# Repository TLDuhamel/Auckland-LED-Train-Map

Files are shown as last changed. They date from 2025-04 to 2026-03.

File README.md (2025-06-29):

# Auckland Live LED Train Map





**You can now support my work by buying this through my store:** [**https://keastudios.co.nz/store/akl-ltm/**](https://keastudios.co.nz/store/akl-ltm/)

A physical, real-time LED map of the Auckland train network, powered by an ESP32-C3 microcontroller. Train movements are displayed using addressable RGB LEDs, with live data fetched over Wi-Fi.

---

## Table of Contents

- [Auckland Live LED Train Map](#auckland-live-led-train-map)
  - [Table of Contents](#table-of-contents)
  - [Features](#features)
  - [Hardware](#hardware)
  - [PCB Design](#pcb-design)
  - [Software / Firmware](#software--firmware)
  - [Getting Started](#getting-started)
  - [Web Installer](#web-installer)
  - [Links](#links)
  - [Contributing](#contributing)
  - [License](#license)

---

PCB Overview Render

## Features

- **Real-time Train Tracking:** Displays the approximate locations of trains on the Auckland network.
- **Addressable LEDs:** ~150 WS2812B-compatible RGB LEDs (1.6x1.5mm) for a vibrant display.
- **Wi-Fi Connectivity:** ESP32-C3's built-in Wi-Fi fetches live train data.
- **Custom PCB:** Designed for JLCPCB manufacturing limits.
- **Open Source:** Hardware and firmware are open source.

---

## Hardware

- **Microcontroller:** ESP32-C3 (RISC-V, 160 MHz, 4 MB Flash, QFN32)
- **LEDs:** ~150 x XL-1615RGBC-WS2812B (1.6mm x 1.5mm)
- **PCB:** 249mm x 66mm, JLCPCB-friendly
- **Antenna:** On-board PCB antenna ([TI CC2430DB design](https://www.ti.com/lit/ug/swru125/swru125.pdf))

ESP32-C3 PCB Render

Pukekohe PCB Render

---

## PCB Design

- Designed in **KiCad V9.0** using [JLCPCB KiCad Library](https://github.com/CDFER/jlcpcb-kicad-library)
- **View Online:** [Interactive PCB Layout (Kicanvas)](https://kicanvas.org/?github=https%3A%2F%2Fgithub.com%2FCDFER%2FAuckland-LED-Train-Map%2Ftree%2Fmain%2FPCB)
- **Source Files:** `/PCB` directory

Schematic

---

## Software / Firmware

The ESP32-C3 firmware is responsible for:

1. Connecting to Wi-Fi
2. Fetching live train data from the [GTFS Realtime Cache API](https://github.com/CDFER/GTFS-Realtime-Cache-Server)
3. Processing data to determine train locations
4. Controlling WS2812B LEDs to display train positions

---

## Getting Started

1. **Flash the Firmware:**
   - Use the [Web Installer](#web-installer) (recommended, no drivers needed)
   - Or flash manually using PlatformIO (`Firmware/` directory)
2. **Connect to Wi-Fi:**
   - On first boot, use the web interface to configure Wi-Fi credentials.
3. **Power the Board:**
   - Use a 5V USB-C power supply capable of at least 1A.
4. **Enjoy the Live Map!**

---

## Web Installer

Easily flash the latest firmware to your ESP32-C3 using your browser:

[Open the Auckland LED Train Map Web Installer](https://cdfer.github.io/Auckland-LED-Train-Map/led-rails.html)

- Works with Chrome, Edge, or any Web Serial-compatible browser
- Follow on-screen instructions to connect and flash your device

---

## Links

- [Web Installer](https://cdfer.github.io/Auckland-LED-Train-Map/led-rails.html)
- [Interactive PCB Viewer](https://kicanvas.org/?github=https%3A%2F%2Fgithub.com%2FCDFER%2FAuckland-LED-Train-Map%2Ftree%2Fmain%2FPCB)
- [GTFS Realtime Cache API](https://github.com/CDFER/GTFS-Realtime-Cache-Server)
- [JLCPCB KiCad Library](https://github.com/CDFER/jlcpcb-kicad-library)

---

## Contributing

Contributions are welcome! Open an issue or submit a pull request for improvements, bug fixes, or feature suggestions.

---

## License

This project is released under the GPL-3.0-or-later license.

© 2025 Chris Dirks

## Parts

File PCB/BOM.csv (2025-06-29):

Reference | Qty | Manufacturer | Part | Description | Value | LCSC
C1 | 1 | AVX | TAJA106K016RNJ | 10uF 16V 3Ω@100kHz ±10% CASE-A-3216-18(mm) Tantalum Capacitors ROHS | 10uF | C7171
C2,C3,C4,C6,C7,C8,C9,C10,C11,C12,C13,C14,C18,C21,C22,C25,C26,C27,C28,C29,C30,C31,C35,C38,C39,C40,C41,C42,C43 | 29 | Samsung Electro-Mechanics | CL05A105KA5NQNC | 25V 1uF X5R ±10% 0402 Multilayer Ceramic Capacitors MLCC - SMD/SMT ROHS | 1uF | C52923
C5,C15 | 2 | AVX | TAJB107K006RNJ | 100uF 6.3V 1.7Ω@100kHz ±10% CASE-B-3528-21(mm) Tantalum Capacitors ROHS | 100uF | C16133
C19,C20 | 2 | FH(Guangdong Fenghua Advanced Tech) | 0402CG270J500NT | 50V 27pF C0G ±5% 0402 Multilayer Ceramic Capacitors MLCC - SMD/SMT ROHS | 27pF | C1557
C36,C37 | 2 | FH(Guangdong Fenghua Advanced Tech) | 0402CG1R5C500NT | 50V 1.5pF C0G 0402 Multilayer Ceramic Capacitors MLCC - SMD/SMT ROHS | 1.5pF | C1552
D1 | 1 | hongjiacheng | MMSZ5227B | Independent Type 3.42V~3.78V 500mW 3.6V SOD-123 Zener Diodes ROHS | MMSZ5227B | C22395553
D2,D10,D11 | 3 | Foshan NationStar Optoelectronics | NCD0805R1 | 25mA Colorless transparent lens 67mcd~195mcd -30°C~+85°C 615nm~630nm Individual diode Red 130° 65mW 1.6V~2.6V 0805 LED Indication - Discrete ROHS | Red | C84256
D4,D5 | 2 | hongjiacheng | MM1W5V6 | Independent Type 5.32V~5.92V 1W 5.6V SOD-123 Zener Diodes ROHS | MM1W5V6 | C22435086
D6,D7 | 2 | MDD（Microdiode Electronics） | SS54 | 40V Independent Type 550mV@5A 5A SMA(DO-214AC) Schottky Diodes ROHS | SS54 | C22452
D8,D9,D12 | 3 | Hubei KENTO Elec | KT-0805G | Emerald 0805 LED Indication - Discrete ROHS | Green | C2297
D13 | 1 | hongjiacheng | H3V3U10B | 5A 25V 125W 9V Bidirectional 3.3V DFN1006-2L ESD and Surge Protection (TVS/ESD) ROHS | H3V3U10B | C20615782
D100,D101,D102,D103,D104,D105,D106,D107,D108,D109,D110,D111,D112,D113,D114,D115,D116,D117,D118,D119,D120,D121,D122,D123,D124,D125,D126,D127,D128,D129,D130,D131,D132,D133,D134,D135,D136,D137,D138,D139,D140,D141,D142,D143,D144,D145,D146,D147,D148,D149,D150,D151,D152,D153,D154,D155,D156,D157,D158,D159,D160,D161,D162,D163,D164,D165,D166,D167,D168,D169,D170,D171,D172,D173,D174,D175,D176,D177,D178,D179,D180,D181,D182,D183,D184,D185,D186,D187,D188,D189,D190,D191,D192,D193,D194,D195,D196,D197,D198,D199,D200,D201,D202,D203,D204,D205,D206,D207,D208,D300,D301,D302,D303,D304,D305,D306,D307,D308,D309,D310,D311,D312,D313,D314,D315,D316,D317,D318,D319,D320,D321,D322,D323,D324,D325,D326,D327,D328,D329,D330,D331,D332,D333,D334,D335,D336,D337,D338,D339,D340,D341,D342,D343,D344 | 154 | XINGLIGHT | XL-1615RGBC-WS2812B-S | 1615 RGB LEDs(Built-in IC) ROHS | XL-1615RGBC-WS2812B-S | C41413180
F1 | 1 | BORN | SMD1206-200/06N | 6V 2A 100A 4A 1206 Resettable Fuses ROHS | Polyfuse, 2A | C6165195
L1,L3 | 2 | Murata Electronics | LQG15HS2N7S02D | 800mA 2.7nH 120mΩ 0402 Inductors (SMD) ROHS | 2.7nH | C77108
L5 | 1 | Sunlord | SDCL1005C15NJTDF | 8@100MHz ±5% 0402 Inductors (SMD) | 15nH,300mA | C27143
Q1 | 1 | hongjiacheng | HL3415A | 20V 5.6A 42mΩ@4.5V,5A 1.3W 620mV@250uA 1 Piece P-Channel SOT-23 MOSFETs ROHS | HL3415A | C28646270
Q2 | 1 | hongjiacheng | MMBT3904 | 40V 200mW 100@10mA,1.0V 200mA NPN SOT-23 Bipolar (BJT) ROHS | MMBT3904 | C7420353
R1,R2,R3,R4,R8,R12,R17,R21 | 8 | UNI-ROYAL(Uniroyal Elec) | 0402WGF1002TCE | 62.5mW Thick Film Resistors 50V ±100ppm/°C ±1% 10kΩ 0402 Chip Resistor - Surface Mount ROHS | 10kΩ | C25744
R7,R18 | 2 | UNI-ROYAL(Uniroyal Elec) | 0402WGF5100TCE | 62.5mW Thick Film Resistors 50V ±100ppm/°C ±1% 510Ω 0402 Chip Resistor - Surface Mount ROHS | 510Ω | C25123
R9,R16,R22,R23,R24,R25 | 6 | UNI-ROYAL(Uniroyal Elec) | 0402WGF1003TCE | 62.5mW Thick Film Resistors 50V ±100ppm/°C ±1% 100kΩ 0402 Chip Resistor - Surface Mount ROHS | 100kΩ | C25741
R10,R15 | 2 | UNI-ROYAL(Uniroyal Elec) | 0402WGF1000TCE | 62.5mW Thick Film Resistors 50V ±1% ±200ppm/°C 100Ω 0402 Chip Resistor - Surface Mount ROHS | 100Ω | C25076
R13,R14,R19,R20 | 4 | UNI-ROYAL(Uniroyal Elec) | 0402WGF5101TCE | 62.5mW Thick Film Resistors 50V ±100ppm/°C ±1% 5.1kΩ 0402 Chip Resistor - Surface Mount ROHS | 5.1kΩ | C25905
S1,S2,S3 | 3 | XKB Connectivity | TS-1187A-B-A-B | None Without 50mA 5.1mm 100000 Times 160gf 12V 5.1mm 1.5mm Round Button Standing paste SPST SMD Tactile Switches ROHS | Tactile Button, 160gf | C318884
U1 | 1 | Torex Semicon | XC6206P332MR-G | 200mA Fixed 3.3V Positive electrode 6V SOT-23-3L Voltage Regulators - Linear, Low Drop Out (LDO) Regulators ROHS | XC6206P332MR | C5446
U2 | 1 | Espressif Systems | ESP32-C3FH4 | RF Module, ESP32 SoC, RISC-V, WiFi 802.11b/n/g, Bluetooth LE 5, QFN32 | ESP32-C3FH4 | C2858491
U3 | 1 | Texas Instruments | SN74LVC4245APWR | 2.7V~3.6V 1 8 4.5V~5.5V TSSOP-24 Translators, Level Shifters ROHS | SN74LVC4245APWR | C7859
U4,U5 | 2 | DEALON | USB-TYPE-C-019 | 3A 1 Horizontal attachment 16P Female -25℃~+85℃ Type-C SMD USB Connectors ROHS | Connector, USB-TYPE-C-16P | C2927039
X1 | 1 | YXC Crystal Oscillators | X322540MPB4SI | 40MHz Surface Mount Crystal 15pF ±10ppm ±20ppm SMD3225-4P Crystals ROHS | 40MHz, 15pF | C9010

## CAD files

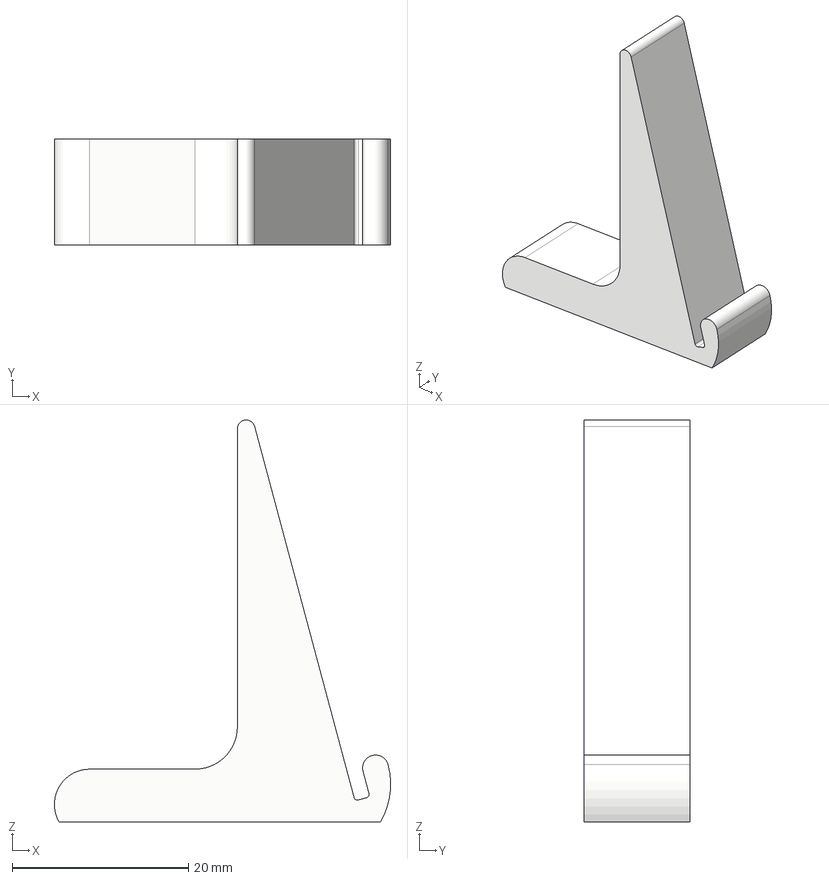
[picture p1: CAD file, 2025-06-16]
Stand/akl-ltm-stand.step
38.2 x 12.0 x 45.6 mm

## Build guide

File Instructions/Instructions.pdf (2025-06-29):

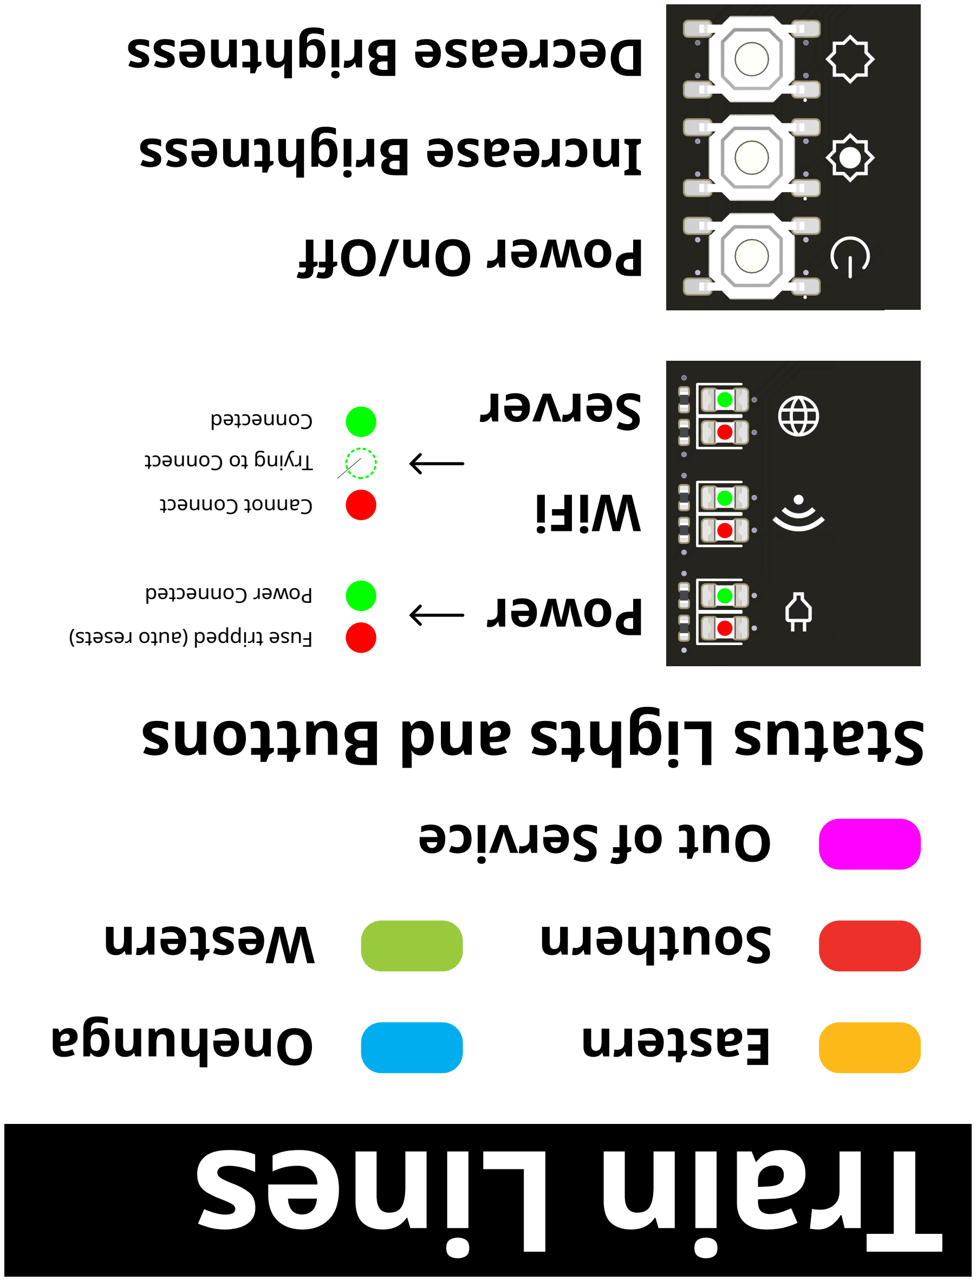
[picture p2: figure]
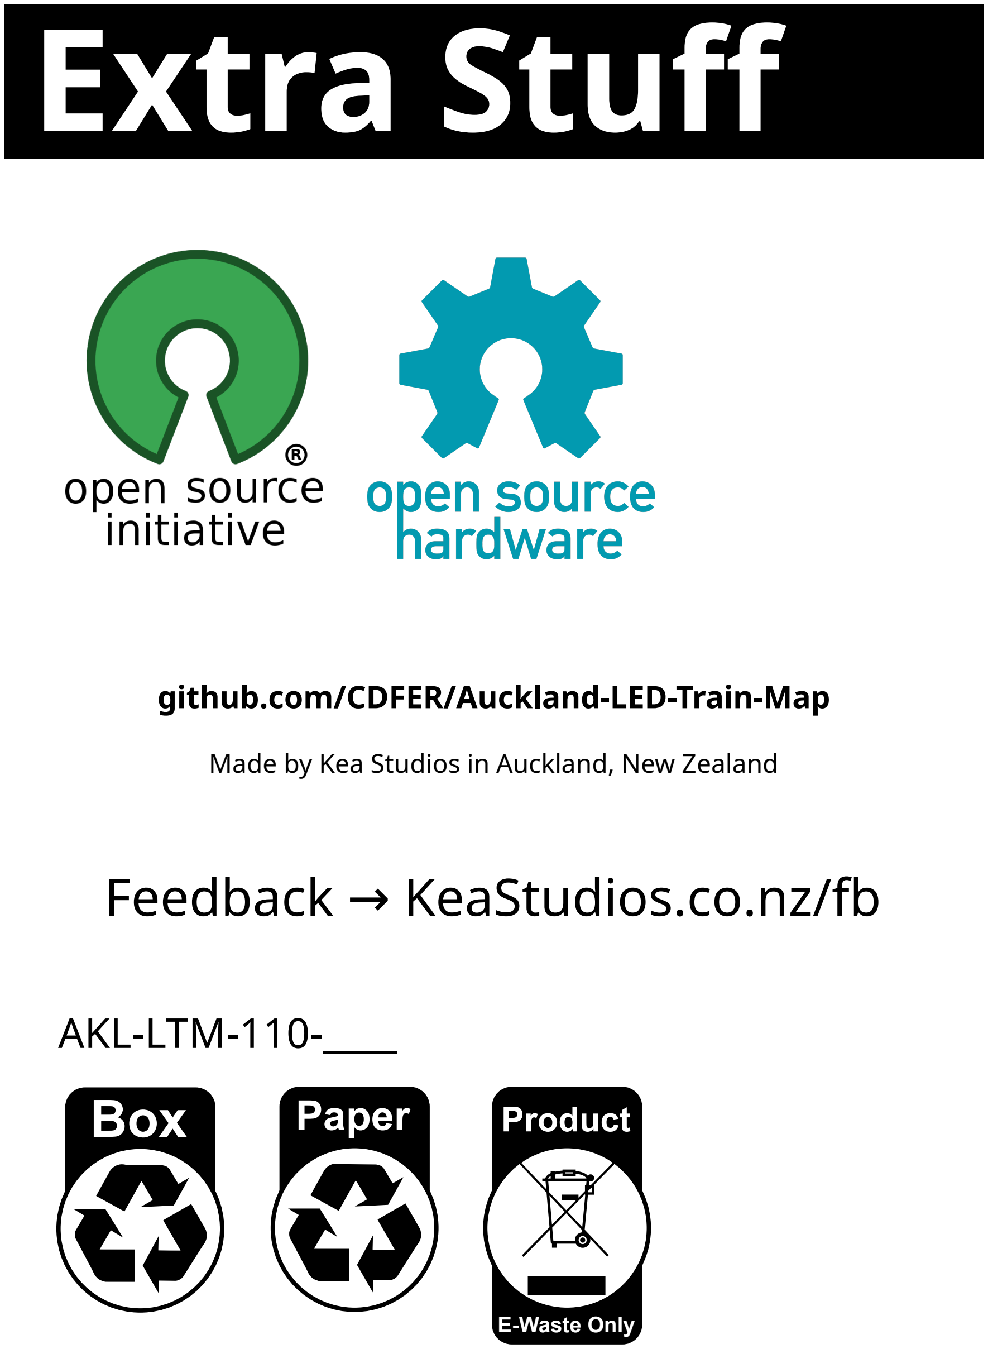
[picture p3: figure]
Extra Stuff; AKL-LTM-110-____; Feedback → KeaStudios.co.nz/fb; Box; Paper; Product; E-Waste Only; github.com/CDFER/Auckland-LED-Train-Map

Made by Kea Studios in Auckland, New Zealand

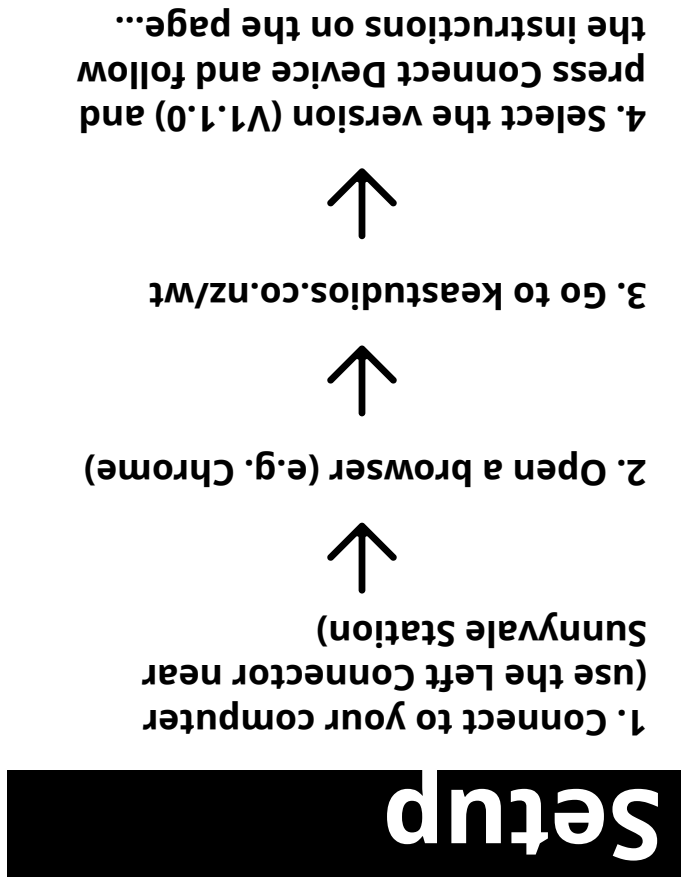
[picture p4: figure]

# Care

## Looking after Your Map

## Specifications

Avoid exposure to temperature extremes, moisture, sand, and dust.

This device is not waterproof. If the product has been in contact with water do not try to dry it in rice. Keep it powered off and place it in a warm place (less than 80°C) for at least a few days before powering it on again.

You can clean the Train map using >95% Isopropyl alcohol and a clean lint free cloth (only while the device is unpowered).

5V ≥1A via USB Type C
Supports WiFi 4 (802.11b/g/n) RoHS (Lead Free)

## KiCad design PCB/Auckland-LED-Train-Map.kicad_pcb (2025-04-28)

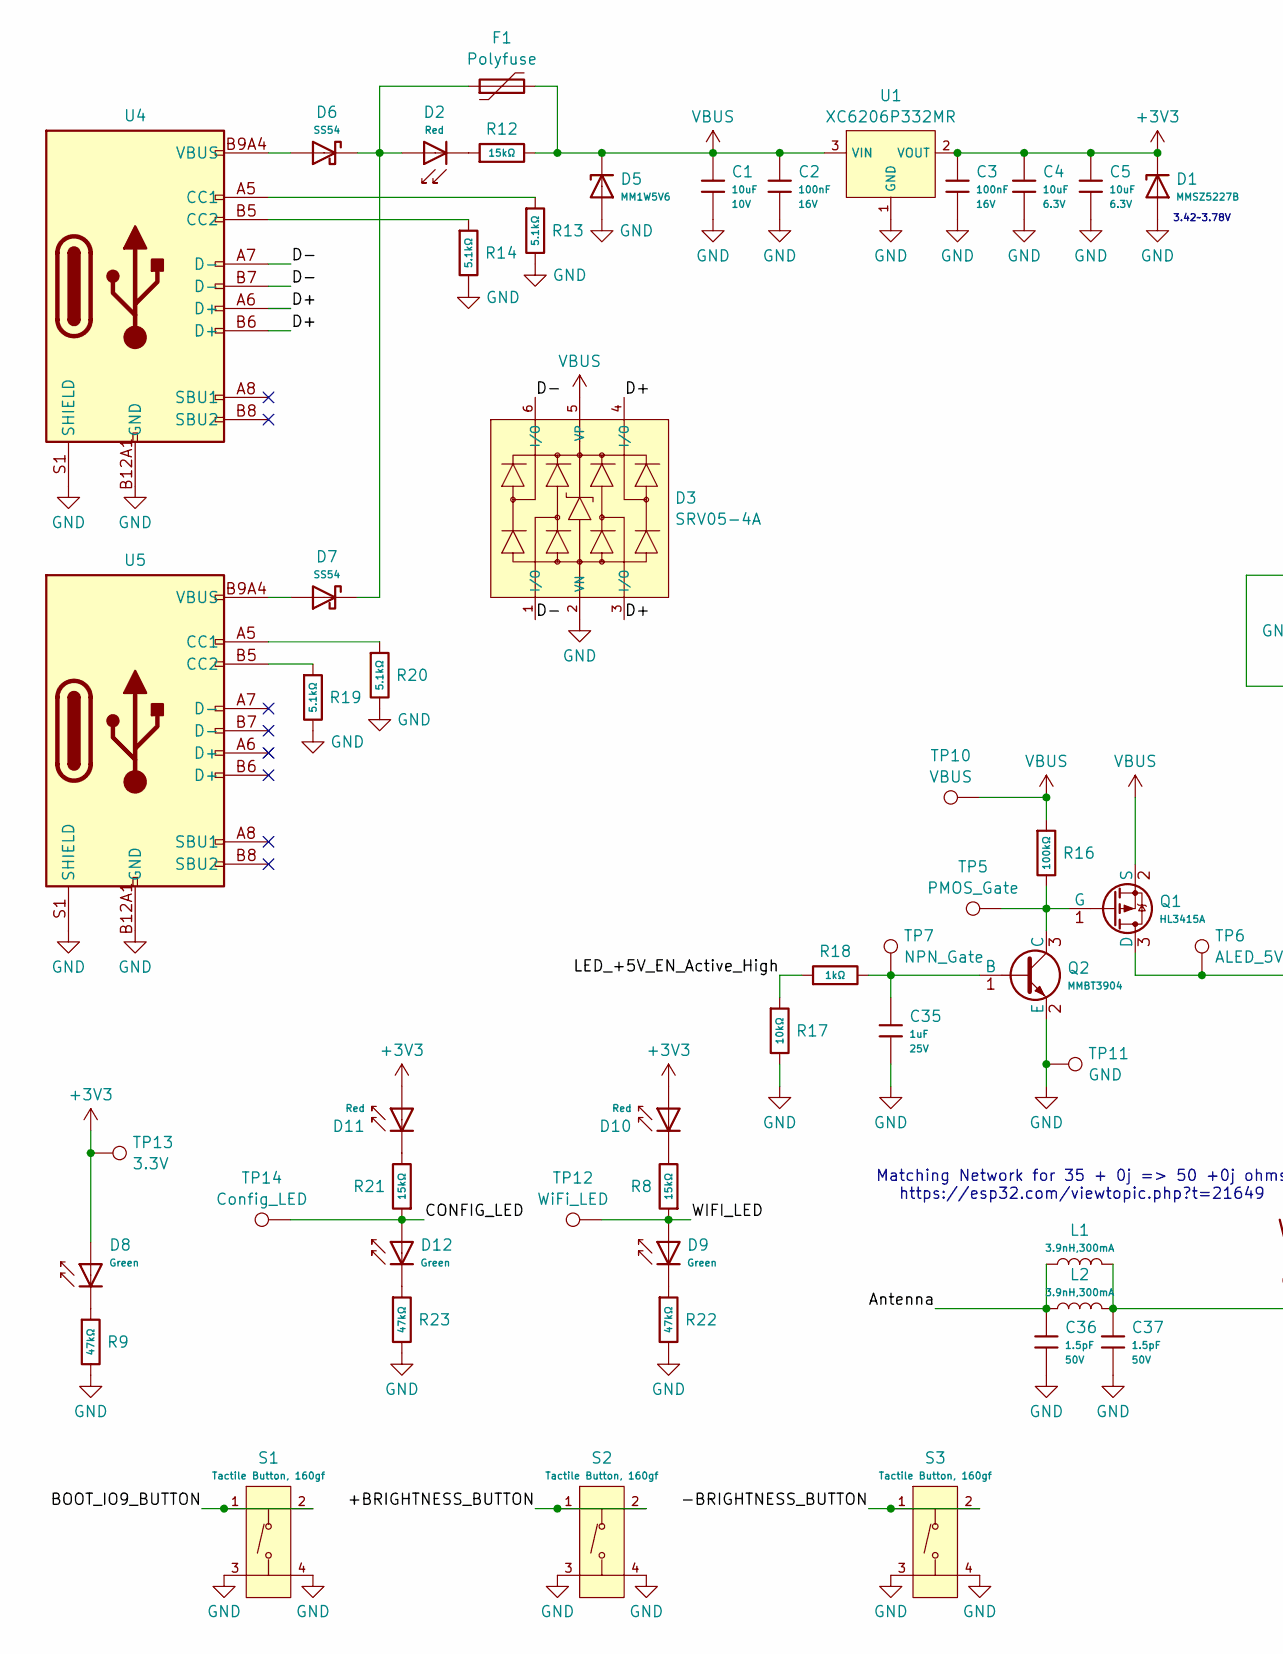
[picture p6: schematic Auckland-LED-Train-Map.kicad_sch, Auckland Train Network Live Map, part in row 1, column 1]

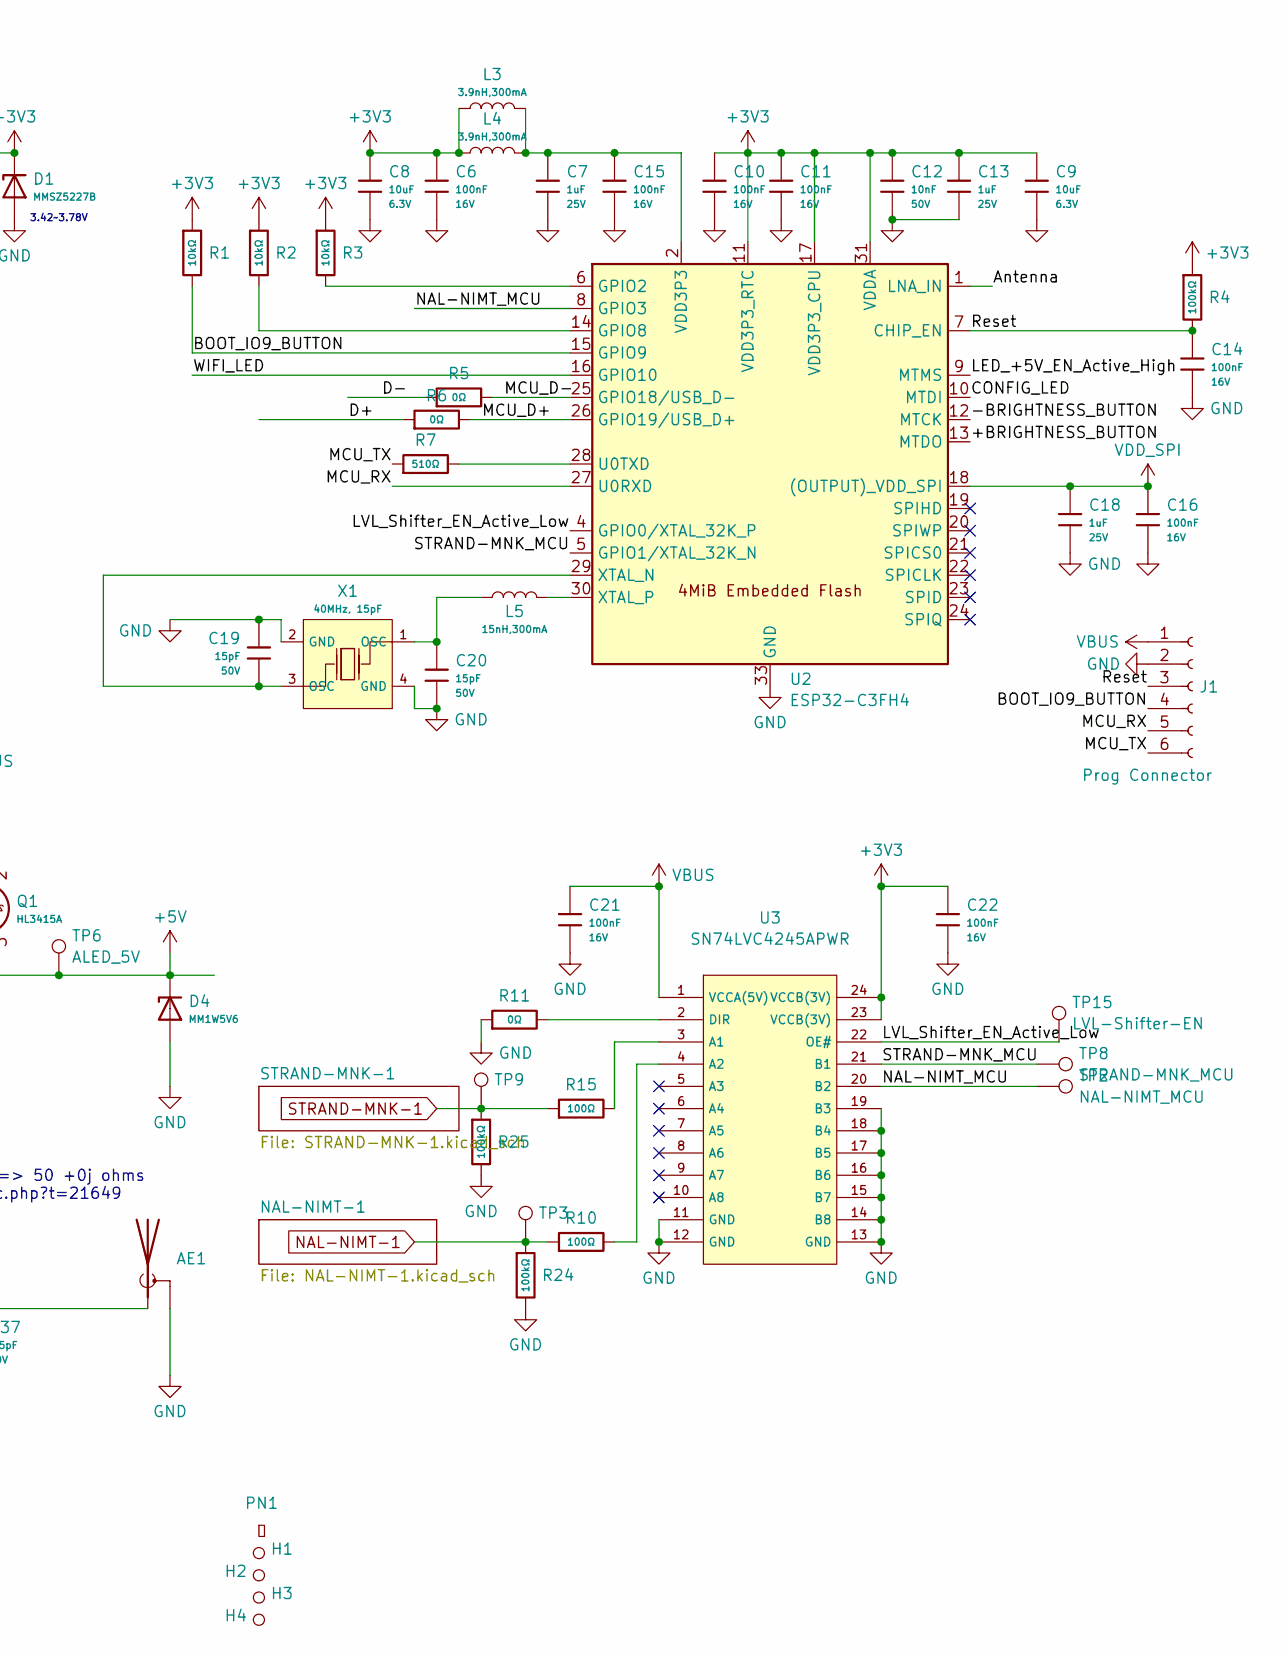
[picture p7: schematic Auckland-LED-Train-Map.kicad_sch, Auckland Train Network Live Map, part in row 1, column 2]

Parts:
AE1: Antenna_Shield; Inverted_F_Antenna_2.4Ghz_1.0mmPCB_TI_CC2430DB.pretty
C1: 10uF; C_0603; Voltage Rated 10V; Tolerance ±10%; Part CL10A106KP8NNNC; LCSC C19702
C2, C3, C6, C10, C11, C14, C15, C16, C21, C22: 100nF; C_0402; Voltage Rated 16V; Tolerance ±10%; Part CL05B104KO5NNNC; LCSC C1525
C4, C5, C8, C9: 10uF; C_0402; Voltage Rated 6.3V; Tolerance ±20%; Part CL05A106MQ5NUNC; LCSC C15525
C7, C13, C18, C35: 1uF; C_0402; Voltage Rated 25V; Tolerance ±10%; Part CL05A105KA5NQNC; LCSC C52923
C12: 10nF; C_0402; Voltage Rated 50V; Tolerance ±10%; Part CL05B103KB5NNNC; LCSC C15195
C19, C20: 15pF; C_0402; Voltage Rated 50V; Tolerance ±5%; Part 0402CG150J500NT; LCSC C1548
C36, C37: 1.5pF; C_0402; Voltage Rated 50V; Part 0402CG1R5C500NT; LCSC C1552
D1: MMSZ5227B; D_SOD-123; Part MMSZ5227B; LCSC C22395553
D2, D10, D11: Red; D_0805; Forward Voltage (VF) 1.6V~2.6V; Part NCD0805R1; LCSC C84256
D3: SRV05-4A; SOT-23-6_L2.9-W1.6-P0.95-LS2.9-BL; Part SRV05-4A; LCSC C20615829
D4, D5: MM1W5V6; D_SOD-123; Part MM1W5V6; LCSC C22435086
D6, D7: SS54; D_SMA; Forward Voltage (Vf@If) 550mV@5A; Reverse Voltage (Vr) 40V; Part SS54; LCSC C22452
D8, D9, D12: Green; D_0805; Part KT-0805G; LCSC C2297
F1: Polyfuse; Fuse_0805_2012Metric_Pad1.15x1.40mm_HandSolder
H1, H2, H3, H4: Hole_Tooling_JLCPCB
J1: Prog Connector
L1, L2, L3, L4: 3.9nH,300mA; L_0402; Part SDCL1005C3N9STDF; LCSC C14033
L5: 15nH,300mA; L_0402; Tolerance ±5%; Part SDCL1005C15NJTDF; LCSC C27143
PN1: Part_Num_JLCPCB
Q1: HL3415A; Q_SOT-23; Part HL3415A; LCSC C28646270
Q2: MMBT3904; Q_SOT-23; Part MMBT3904; LCSC C7420353
R1, R2, R3, R17: 10kΩ; R_0402; Overload Voltage (Max) 50V; Tolerance ±1%; Part 0402WGF1002TCE; LCSC C25744
R4, R16, R24, R25: 100kΩ; R_0402; Overload Voltage (Max) 50V; Tolerance ±1%; Part 0402WGF1003TCE; LCSC C25741
R5, R6, R11: 0Ω; R_0402; Overload Voltage (Max) 50V; Tolerance ±1%; Part 0402WGF0000TCE; LCSC C17168
R7: 510Ω; R_0402; Overload Voltage (Max) 50V; Tolerance ±1%; Part 0402WGF5100TCE; LCSC C25123
R8, R12, R21: 15kΩ; R_0402; Overload Voltage (Max) 50V; Tolerance ±1%; Part 0402WGF1502TCE; LCSC C25756
R9, R22, R23: 47kΩ; R_0402; Overload Voltage (Max) 50V; Tolerance ±1%; Part 0402WGF4702TCE; LCSC C25792
R10, R15: 100Ω; R_0402; Overload Voltage (Max) 50V; Tolerance ±1%; Part 0402WGF1000TCE; LCSC C25076
R13, R14, R19, R20: 5.1kΩ; R_0402; Overload Voltage (Max) 50V; Tolerance ±1%; Part 0402WGF5101TCE; LCSC C25905
R18: 1kΩ; R_0402; Overload Voltage (Max) 50V; Tolerance ±1%; Part 0402WGF1001TCE; LCSC C11702
S1, S2, S3: Tactile Button, 160gf; SW-SMD_4P-L5.1-W5.1-P3.70-LS6.5-TL-2; Voltage Rating (Dc) 12V; Part TS-1187A-B-A-B; LCSC C318884
TP2: NAL-NIMT_MCU; TestPoint_Pad_D1.0mm
TP3: NAL-NIMT_LED; TestPoint_Pad_D1.0mm
TP5: PMOS_Gate; TestPoint_Pad_D1.0mm
TP6: ALED_5V; TestPoint_Pad_D1.0mm
TP7: NPN_Gate; TestPoint_Pad_D1.0mm
TP8: STRAND-MNK_MCU; TestPoint_Pad_D1.0mm
TP9: STRAND-MNK_LED; TestPoint_Pad_D1.0mm
TP10: VBUS; TestPoint_Pad_D1.0mm
TP11: GND; TestPoint_Pad_D1.0mm
TP12: WiFi_LED; TestPoint_Pad_D1.0mm
TP13: 3.3V; TestPoint_Pad_D1.0mm
TP14: Config_LED; TestPoint_Pad_D1.0mm
TP15: LVL-Shifter-EN; TestPoint_Pad_D1.0mm
U1: XC6206P332MR; SOT-23-3_L2.9-W1.6-P1.90-LS2.8-BR; Output Voltage 3.3V; Dropout Voltage 680mV@(100mA); Part XC6206P332MR-G; LCSC C5446
U2: ESP32-C3FH4; QFN-32-1EP_5x5mm_P0.5mm_EP3.7x3.7mm_ThermalVias; LCSC C2858491
U3: SN74LVC4245APWR; TSSOP-24_L7.8-W4.4-P0.65-LS6.4-BL; Part SN74LVC4245APWR; LCSC C7859
U4, U5: Connector, USB-TYPE-C-16P; TYPE-C-SMD_HX-TYPE-C-16PIN; LCSC C2927039
X1: 40MHz, 15pF; OSC-SMD_4P-L3.2-W2.5-BL_SIT8008BI; PartID X322540MPB4SI; LCSC C9010

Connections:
+3V3: C3.1, C4.1, C5.1, C6.1, C8.1, C9.1, C10.1, C11.1, C12.1, C13.1, C22.1, D1.1, D8.2, D10.2, D11.2, L3.1, L4.1, R1.1, R2.1, R3.1, R4.1, TP13.1, U1.2 (VOUT), U2.11 (VDD3P3_RTC), U2.17 (VDD3P3_CPU), U2.31 (VDDA), U2.32 (VDDA), U3.23 (VCCB(3V)), U3.24 (VCCB(3V))
+5V: D4.1, Q1.3 (D), TP6.1; also elsewhere on the board
/+BRIGHTNESS_BUTTON: S2.1 (A), S2.2 (B), U2.13 (MTDO)
/-BRIGHTNESS_BUTTON: S3.1 (A), S3.2 (B), U2.12 (MTCK)
/Antenna: C36.1, L1.1, L2.1, U2.1 (LNA_IN)
/BOOT_IO9_BUTTON: J1.4, R1.2, S1.1 (A), S1.2 (B), U2.15 (GPIO9)
/CONFIG_LED: D12.2, R21.1, TP14.1, U2.10 (MTDI)
/D+: D3.3 (I/O), D3.4 (I/O), R6.1, U4.A6 (D+), U4.B6 (D+)
/D-: D3.1 (I/O), D3.6 (I/O), R5.1, U4.A7 (D-), U4.B7 (D-)
/LED_+5V_EN_Active_High: R17.1, R18.1, U2.9 (MTMS)
/LVL_Shifter_EN_Active_Low: TP15.1, U2.4 (GPIO0/XTAL_32K_P), U3.22 (OE#)
/MCU_D+: R6.2, U2.26 (GPIO19/USB_D+)
/MCU_D-: R5.2, U2.25 (GPIO18/USB_D-)
/MCU_RX: J1.5, U2.27 (U0RXD)
/MCU_TX: J1.6, R7.1
/NAL-NIMT_MCU: TP2.1, U2.8 (GPIO3), U3.20 (B2)
/Reset: C14.1, J1.3, R4.2, U2.7 (CHIP_EN)
/STRAND-MNK_MCU: TP8.1, U2.5 (GPIO1/XTAL_32K_N), U3.21 (B1)
/WIFI_LED: D9.2, R8.1, TP12.1, U2.16 (GPIO10)
GND: AE1.2 (Shield), C1.2, C2.2, C3.2, C4.2, C5.2, C6.2, C7.2, C8.2, C9.2, C10.2, C11.2, C12.2, C13.2, C14.2, C15.2, C16.2, C18.2, C19.2, C20.2, C21.2, C22.2, C35.2, C36.2, C37.2, D1.2, D3.2 (VN), D4.2, D5.2, J1.2, Q2.2 (E), R9.2, R11.1, R13.2, R14.2, R17.2, R19.2, R20.2, R22.2, R23.2, R24.2, R25.2, S1.3 (C), S1.4 (D), S2.3 (C), S2.4 (D), S3.3 (C), S3.4 (D), TP11.1, U1.1 (GND), U2.33 (GND), U3.11 (GND), U3.12 (GND), U3.13 (GND), U3.14 (B8), U3.15 (B7), U3.16 (B6), U3.17 (B5), U3.18 (B4), U3.19 (B3), U4.A12B1 (GND), U4.B12A1 (GND), U4.S1 (SHIELD), U5.A12B1 (GND), U5.B12A1 (GND), U5.S1 (SHIELD), X1.2 (GND), X1.4 (GND); also elsewhere on the board
NAL-NIMT-1: R10.1, R24.1, TP3.1; also elsewhere on the board
unnamed: AE1.1 (A), C37.1, L1.2, L2.2
unnamed: C7.1, C15.1, L3.2, L4.2, U2.2 (VDD3P3), U2.3 (VDD3P3)
unnamed: C20.1, L5.1, X1.1 (OSC)
unnamed: D2.1, R12.1
unnamed: D2.2, D6.1, D7.1, F1.1
unnamed: D6.2, U4.A9B4 (VBUS), U4.B9A4 (VBUS)
unnamed: D7.2, U5.A9B4 (VBUS), U5.B9A4 (VBUS)
unnamed: D8.1, R9.1
unnamed: D9.1, R22.1
unnamed: D10.1, R8.2
unnamed: D11.1, R21.2
unnamed: D12.1, R23.1
unnamed: Q1.1 (G), Q2.3 (C), R16.2, TP5.1
unnamed: C35.1, Q2.1 (B), R18.2, TP7.1
unnamed: R3.2, U2.6 (GPIO2)
unnamed: R2.2, U2.14 (GPIO8)
unnamed: R7.2, U2.28 (U0TXD)
unnamed: C19.1, U2.29 (XTAL_N), X1.3 (OSC)
unnamed: L5.2, U2.30 (XTAL_P)
unnamed: R15.2, U3.3 (A1)
unnamed: R10.2, U3.4 (A2)
unnamed: R11.2, U3.2 (DIR)
unnamed: R13.1, U4.A5 (CC1)
unnamed: R14.1, U4.B5 (CC2)
unnamed: R20.1, U5.A5 (CC1)
unnamed: R19.1, U5.B5 (CC2)
STRAND-MNK-1: R15.1, R25.1, TP9.1; also elsewhere on the board
VBUS: C1.1, C2.1, C21.1, D3.5 (VP), D5.1, F1.2, J1.1, Q1.2 (S), R12.2, R16.1, TP10.1, U1.3 (VIN), U3.1 (VCCA(5V))
VDD_SPI: C16.1, C18.1, U2.18 ((OUTPUT)_VDD_SPI)

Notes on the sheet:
Matching Network for 35 + 0j => 50 +0j ohms https://esp32.com/viewtopic.php?t=21649
3.42~3.78V

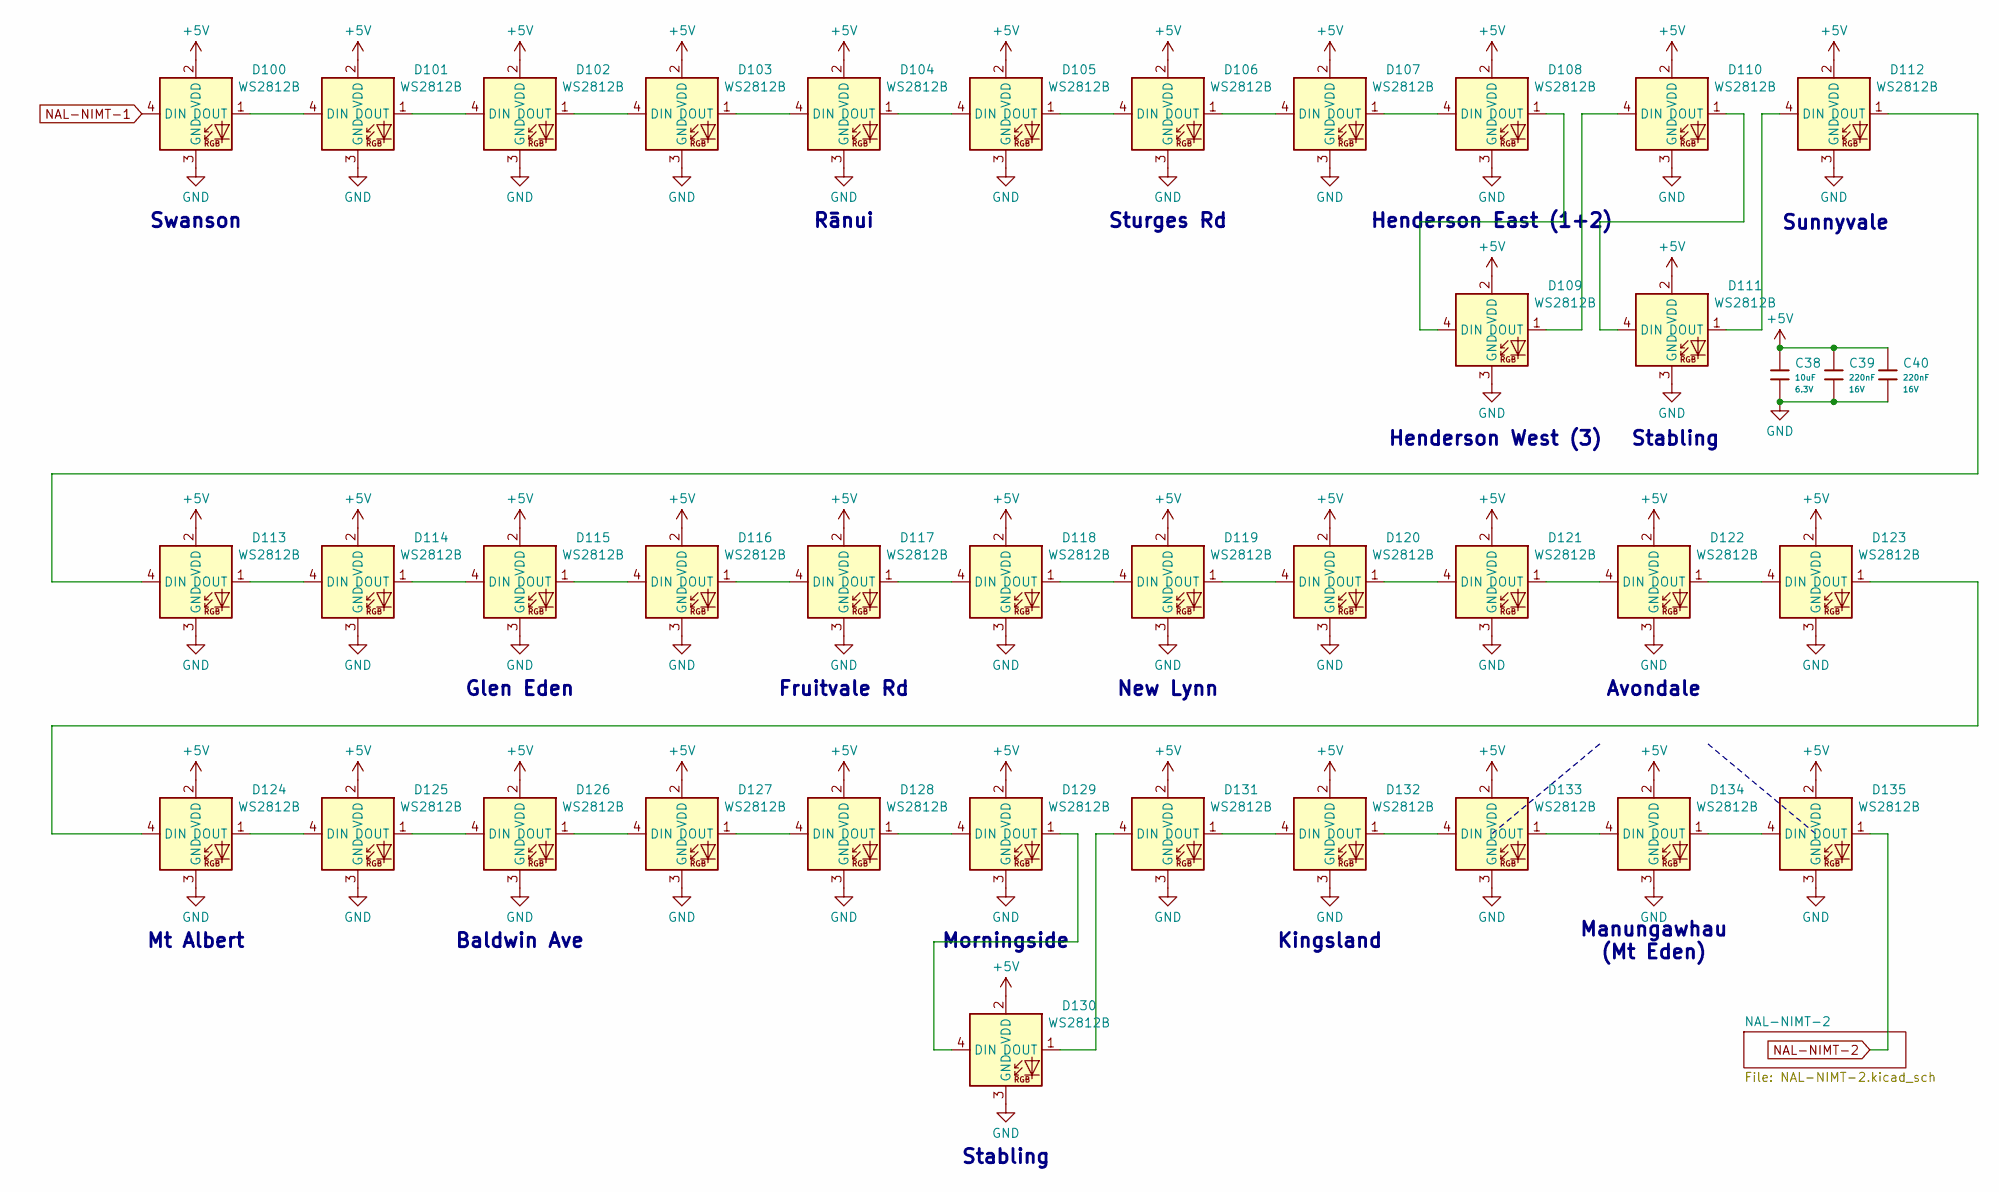
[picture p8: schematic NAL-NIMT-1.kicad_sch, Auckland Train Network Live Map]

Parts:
C38: 10uF; C_0402; Voltage Rated 6.3V; Tolerance ±20%; Part CL05A106MQ5NUNC; LCSC C15525
C39, C40: 220nF; C_0402; Voltage Rated 16V; Tolerance ±10%; Part CL05B224KO5NNNC; LCSC C16772
D100, D101, D102, D103, D104, D105, D106, D107, D108, D109, D110, D111, D112, D113, D114, D115, D116, D117, D118, D119, D120, D121, D122, D123, D124, D125, D126, D127, D128, D129, D130, D131, D132, D133, D134, D135: WS2812B; LED-SMD_4P-L1.6-W1.5_XL-1615RGBC-WS2812B; LCSC C5349954

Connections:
+5V: C38.1, C39.1, C40.1, D100.2 (VDD), D101.2 (VDD), D102.2 (VDD), D103.2 (VDD), D104.2 (VDD), D105.2 (VDD), D106.2 (VDD), D107.2 (VDD), D108.2 (VDD), D109.2 (VDD), D110.2 (VDD), D111.2 (VDD), D112.2 (VDD), D113.2 (VDD), D114.2 (VDD), D115.2 (VDD), D116.2 (VDD), D117.2 (VDD), D118.2 (VDD), D119.2 (VDD), D120.2 (VDD), D121.2 (VDD), D122.2 (VDD), D123.2 (VDD), D124.2 (VDD), D125.2 (VDD), D126.2 (VDD), D127.2 (VDD), D128.2 (VDD), D129.2 (VDD), D130.2 (VDD), D131.2 (VDD), D132.2 (VDD), D133.2 (VDD), D134.2 (VDD), D135.2 (VDD); also elsewhere on the board
GND: C38.2, C39.2, C40.2, D100.3 (GND), D101.3 (GND), D102.3 (GND), D103.3 (GND), D104.3 (GND), D105.3 (GND), D106.3 (GND), D107.3 (GND), D108.3 (GND), D109.3 (GND), D110.3 (GND), D111.3 (GND), D112.3 (GND), D113.3 (GND), D114.3 (GND), D115.3 (GND), D116.3 (GND), D117.3 (GND), D118.3 (GND), D119.3 (GND), D120.3 (GND), D121.3 (GND), D122.3 (GND), D123.3 (GND), D124.3 (GND), D125.3 (GND), D126.3 (GND), D127.3 (GND), D128.3 (GND), D129.3 (GND), D130.3 (GND), D131.3 (GND), D132.3 (GND), D133.3 (GND), D134.3 (GND), D135.3 (GND); also elsewhere on the board
NAL-NIMT-1: D100.4 (DIN); also elsewhere on the board
NAL-NIMT-2: D135.1 (DOUT); also elsewhere on the board
unnamed: D100.1 (DOUT), D101.4 (DIN)
unnamed: D101.1 (DOUT), D102.4 (DIN)
unnamed: D102.1 (DOUT), D103.4 (DIN)
unnamed: D103.1 (DOUT), D104.4 (DIN)
unnamed: D104.1 (DOUT), D105.4 (DIN)
unnamed: D105.1 (DOUT), D106.4 (DIN)
unnamed: D106.1 (DOUT), D107.4 (DIN)
unnamed: D107.1 (DOUT), D108.4 (DIN)
unnamed: D108.1 (DOUT), D109.4 (DIN)
unnamed: D109.1 (DOUT), D110.4 (DIN)
unnamed: D110.1 (DOUT), D111.4 (DIN)
unnamed: D111.1 (DOUT), D112.4 (DIN)
unnamed: D112.1 (DOUT), D113.4 (DIN)
unnamed: D113.1 (DOUT), D114.4 (DIN)
unnamed: D114.1 (DOUT), D115.4 (DIN)
unnamed: D115.1 (DOUT), D116.4 (DIN)
unnamed: D116.1 (DOUT), D117.4 (DIN)
unnamed: D117.1 (DOUT), D118.4 (DIN)
unnamed: D118.1 (DOUT), D119.4 (DIN)
unnamed: D119.1 (DOUT), D120.4 (DIN)
unnamed: D120.1 (DOUT), D121.4 (DIN)
unnamed: D121.1 (DOUT), D122.4 (DIN)
unnamed: D122.1 (DOUT), D123.4 (DIN)
unnamed: D123.1 (DOUT), D124.4 (DIN)
unnamed: D124.1 (DOUT), D125.4 (DIN)
unnamed: D125.1 (DOUT), D126.4 (DIN)
unnamed: D126.1 (DOUT), D127.4 (DIN)
unnamed: D127.1 (DOUT), D128.4 (DIN)
unnamed: D128.1 (DOUT), D129.4 (DIN)
unnamed: D129.1 (DOUT), D130.4 (DIN)
unnamed: D130.1 (DOUT), D131.4 (DIN)
unnamed: D131.1 (DOUT), D132.4 (DIN)
unnamed: D132.1 (DOUT), D133.4 (DIN)
unnamed: D133.1 (DOUT), D134.4 (DIN)
unnamed: D134.1 (DOUT), D135.4 (DIN)

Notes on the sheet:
Henderson East (1+2)
Rānui
Henderson West (3)
Stabling
Mt Albert
Baldwin Ave
New Lynn
Kingsland
Manungawhau (Mt Eden)
Fruitvale Rd
Sunnyvale
Swanson
Sturges Rd
Glen Eden
Avondale
Morningside

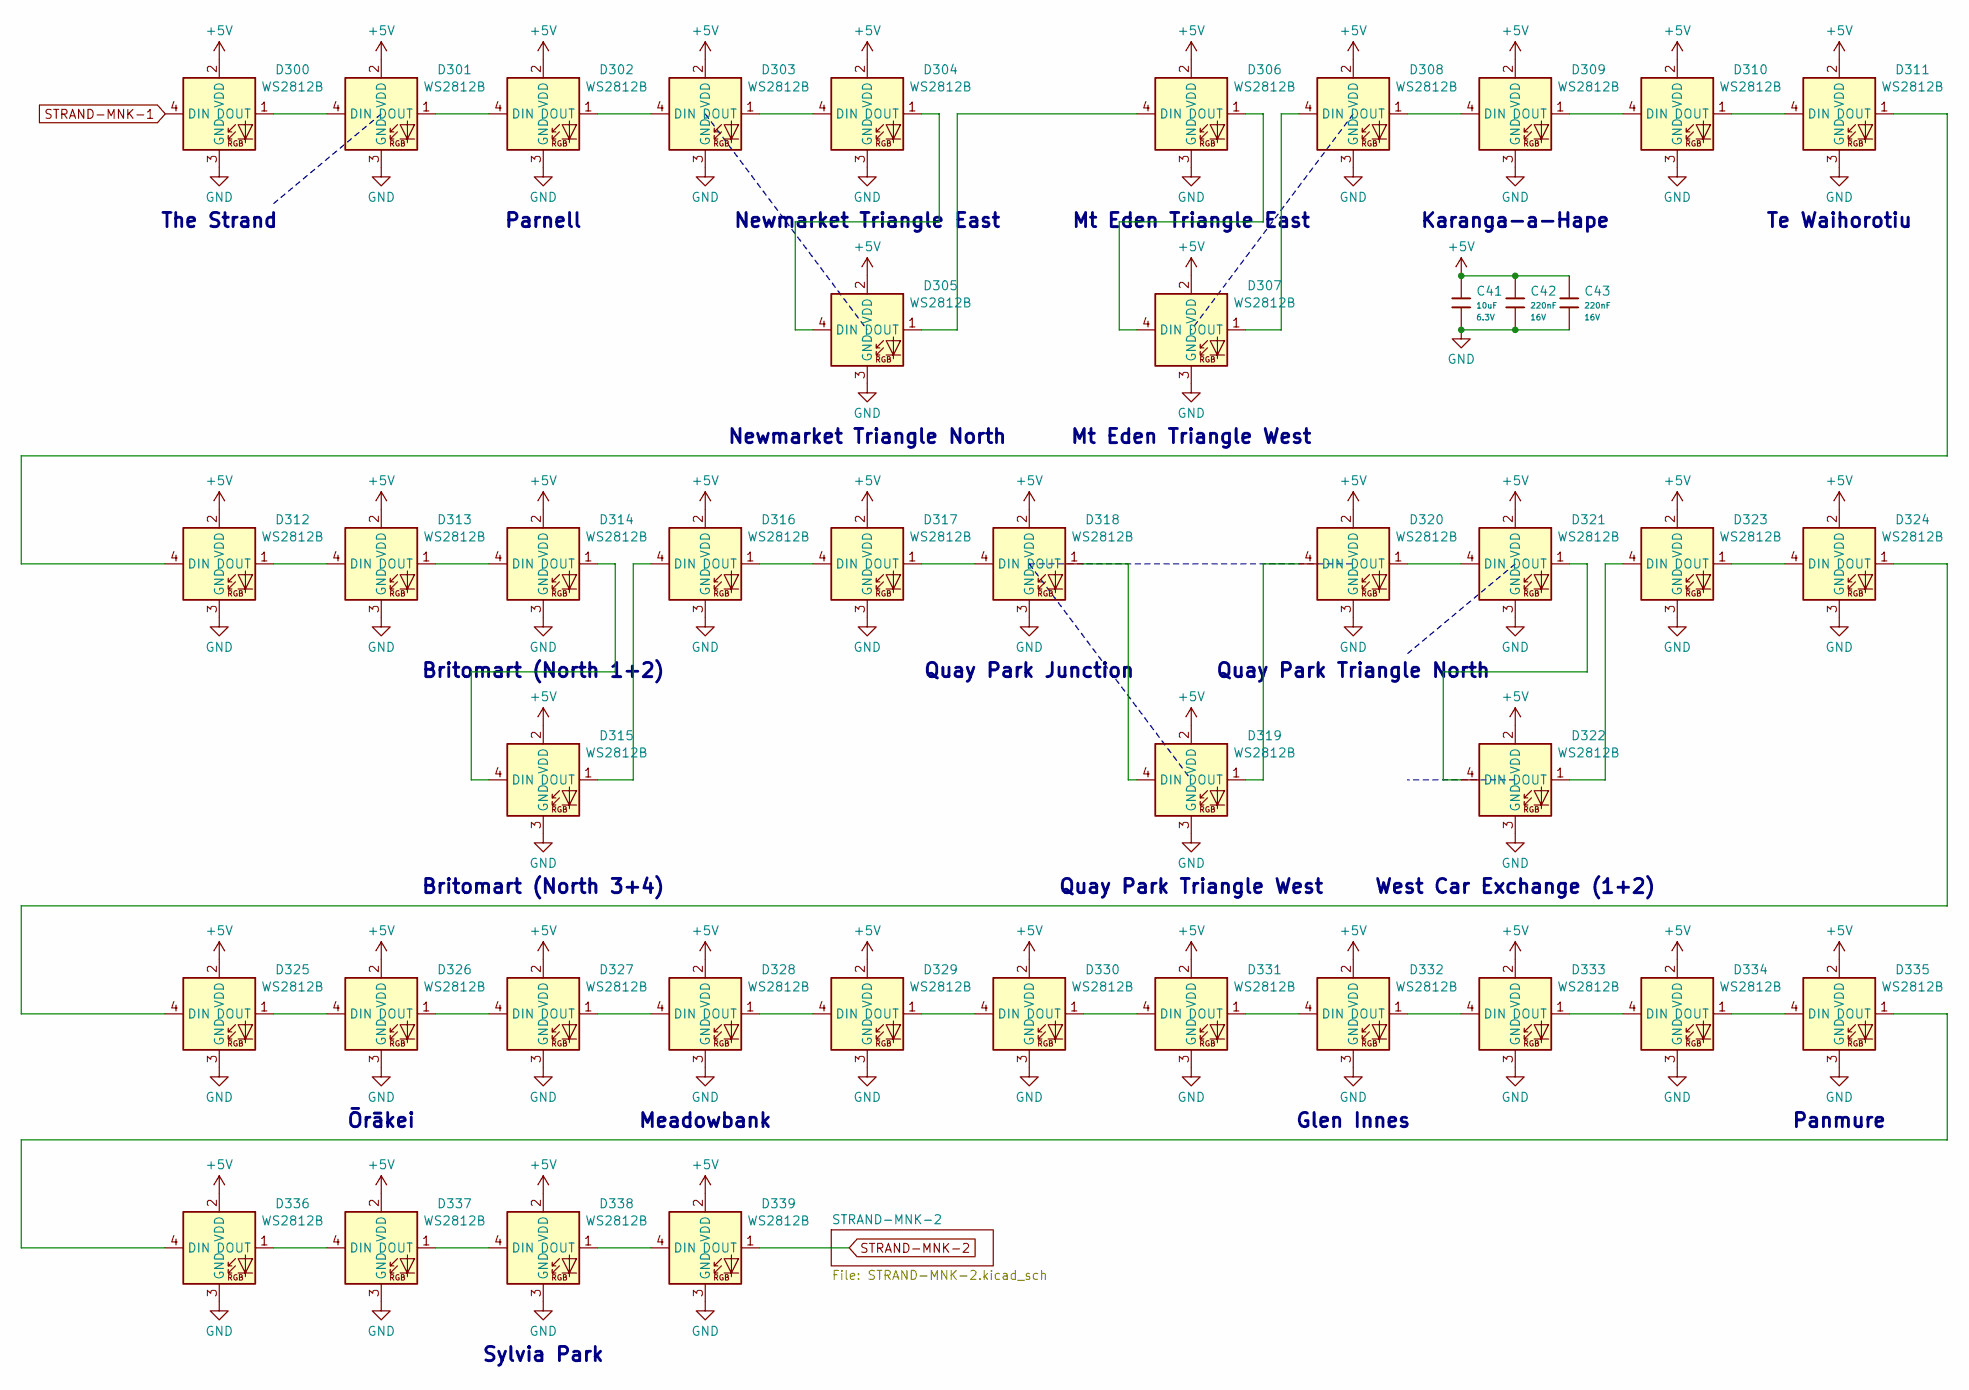
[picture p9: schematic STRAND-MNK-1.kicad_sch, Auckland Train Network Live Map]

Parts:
C41: 10uF; C_0402; Voltage Rated 6.3V; Tolerance ±20%; Part CL05A106MQ5NUNC; LCSC C15525
C42, C43: 220nF; C_0402; Voltage Rated 16V; Tolerance ±10%; Part CL05B224KO5NNNC; LCSC C16772
D300, D301, D302, D303, D304, D305, D306, D307, D308, D309, D310, D311, D312, D313, D314, D315, D316, D317, D318, D319, D320, D321, D322, D323, D324, D325, D326, D327, D328, D329, D330, D331, D332, D333, D334, D335, D336, D337, D338, D339: WS2812B; LED-SMD_4P-L1.6-W1.5_XL-1615RGBC-WS2812B; LCSC C5349954

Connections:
+5V: C41.1, C42.1, C43.1, D300.2 (VDD), D301.2 (VDD), D302.2 (VDD), D303.2 (VDD), D304.2 (VDD), D305.2 (VDD), D306.2 (VDD), D307.2 (VDD), D308.2 (VDD), D309.2 (VDD), D310.2 (VDD), D311.2 (VDD), D312.2 (VDD), D313.2 (VDD), D314.2 (VDD), D315.2 (VDD), D316.2 (VDD), D317.2 (VDD), D318.2 (VDD), D319.2 (VDD), D320.2 (VDD), D321.2 (VDD), D322.2 (VDD), D323.2 (VDD), D324.2 (VDD), D325.2 (VDD), D326.2 (VDD), D327.2 (VDD), D328.2 (VDD), D329.2 (VDD), D330.2 (VDD), D331.2 (VDD), D332.2 (VDD), D333.2 (VDD), D334.2 (VDD), D335.2 (VDD), D336.2 (VDD), D337.2 (VDD), D338.2 (VDD), D339.2 (VDD); also elsewhere on the board
GND: C41.2, C42.2, C43.2, D300.3 (GND), D301.3 (GND), D302.3 (GND), D303.3 (GND), D304.3 (GND), D305.3 (GND), D306.3 (GND), D307.3 (GND), D308.3 (GND), D309.3 (GND), D310.3 (GND), D311.3 (GND), D312.3 (GND), D313.3 (GND), D314.3 (GND), D315.3 (GND), D316.3 (GND), D317.3 (GND), D318.3 (GND), D319.3 (GND), D320.3 (GND), D321.3 (GND), D322.3 (GND), D323.3 (GND), D324.3 (GND), D325.3 (GND), D326.3 (GND), D327.3 (GND), D328.3 (GND), D329.3 (GND), D330.3 (GND), D331.3 (GND), D332.3 (GND), D333.3 (GND), D334.3 (GND), D335.3 (GND), D336.3 (GND), D337.3 (GND), D338.3 (GND), D339.3 (GND); also elsewhere on the board
unnamed: D300.1 (DOUT), D301.4 (DIN)
unnamed: D301.1 (DOUT), D302.4 (DIN)
unnamed: D302.1 (DOUT), D303.4 (DIN)
unnamed: D303.1 (DOUT), D304.4 (DIN)
unnamed: D304.1 (DOUT), D305.4 (DIN)
unnamed: D305.1 (DOUT), D306.4 (DIN)
unnamed: D306.1 (DOUT), D307.4 (DIN)
unnamed: D307.1 (DOUT), D308.4 (DIN)
unnamed: D308.1 (DOUT), D309.4 (DIN)
unnamed: D309.1 (DOUT), D310.4 (DIN)
unnamed: D310.1 (DOUT), D311.4 (DIN)
unnamed: D311.1 (DOUT), D312.4 (DIN)
unnamed: D312.1 (DOUT), D313.4 (DIN)
unnamed: D313.1 (DOUT), D314.4 (DIN)
unnamed: D314.1 (DOUT), D315.4 (DIN)
unnamed: D315.1 (DOUT), D316.4 (DIN)
unnamed: D316.1 (DOUT), D317.4 (DIN)
unnamed: D317.1 (DOUT), D318.4 (DIN)
unnamed: D318.1 (DOUT), D319.4 (DIN)
unnamed: D319.1 (DOUT), D320.4 (DIN)
unnamed: D320.1 (DOUT), D321.4 (DIN)
unnamed: D321.1 (DOUT), D322.4 (DIN)
unnamed: D322.1 (DOUT), D323.4 (DIN)
unnamed: D323.1 (DOUT), D324.4 (DIN)
unnamed: D324.1 (DOUT), D325.4 (DIN)
unnamed: D325.1 (DOUT), D326.4 (DIN)
unnamed: D326.1 (DOUT), D327.4 (DIN)
unnamed: D327.1 (DOUT), D328.4 (DIN)
unnamed: D328.1 (DOUT), D329.4 (DIN)
unnamed: D329.1 (DOUT), D330.4 (DIN)
unnamed: D330.1 (DOUT), D331.4 (DIN)
unnamed: D331.1 (DOUT), D332.4 (DIN)
unnamed: D332.1 (DOUT), D333.4 (DIN)
unnamed: D333.1 (DOUT), D334.4 (DIN)
unnamed: D334.1 (DOUT), D335.4 (DIN)
unnamed: D335.1 (DOUT), D336.4 (DIN)
unnamed: D336.1 (DOUT), D337.4 (DIN)
unnamed: D337.1 (DOUT), D338.4 (DIN)
unnamed: D338.1 (DOUT), D339.4 (DIN)
STRAND-MNK-1: D300.4 (DIN); also elsewhere on the board
STRAND-MNK-2: D339.1 (DOUT); also elsewhere on the board

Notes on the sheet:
Britomart (North 1+2)
Quay Park Triangle North
Panmure
Parnell
Te Waihorotiu
Meadowbank
Mt Eden Triangle West
Newmarket Triangle East
Quay Park Junction
Quay Park Triangle West
Ōrākei
Glen Innes
Newmarket Triangle North
Mt Eden Triangle East
The Strand
Sylvia Park
Karanga-a-Hape
West Car Exchange (1+2)
Britomart (North 3+4)

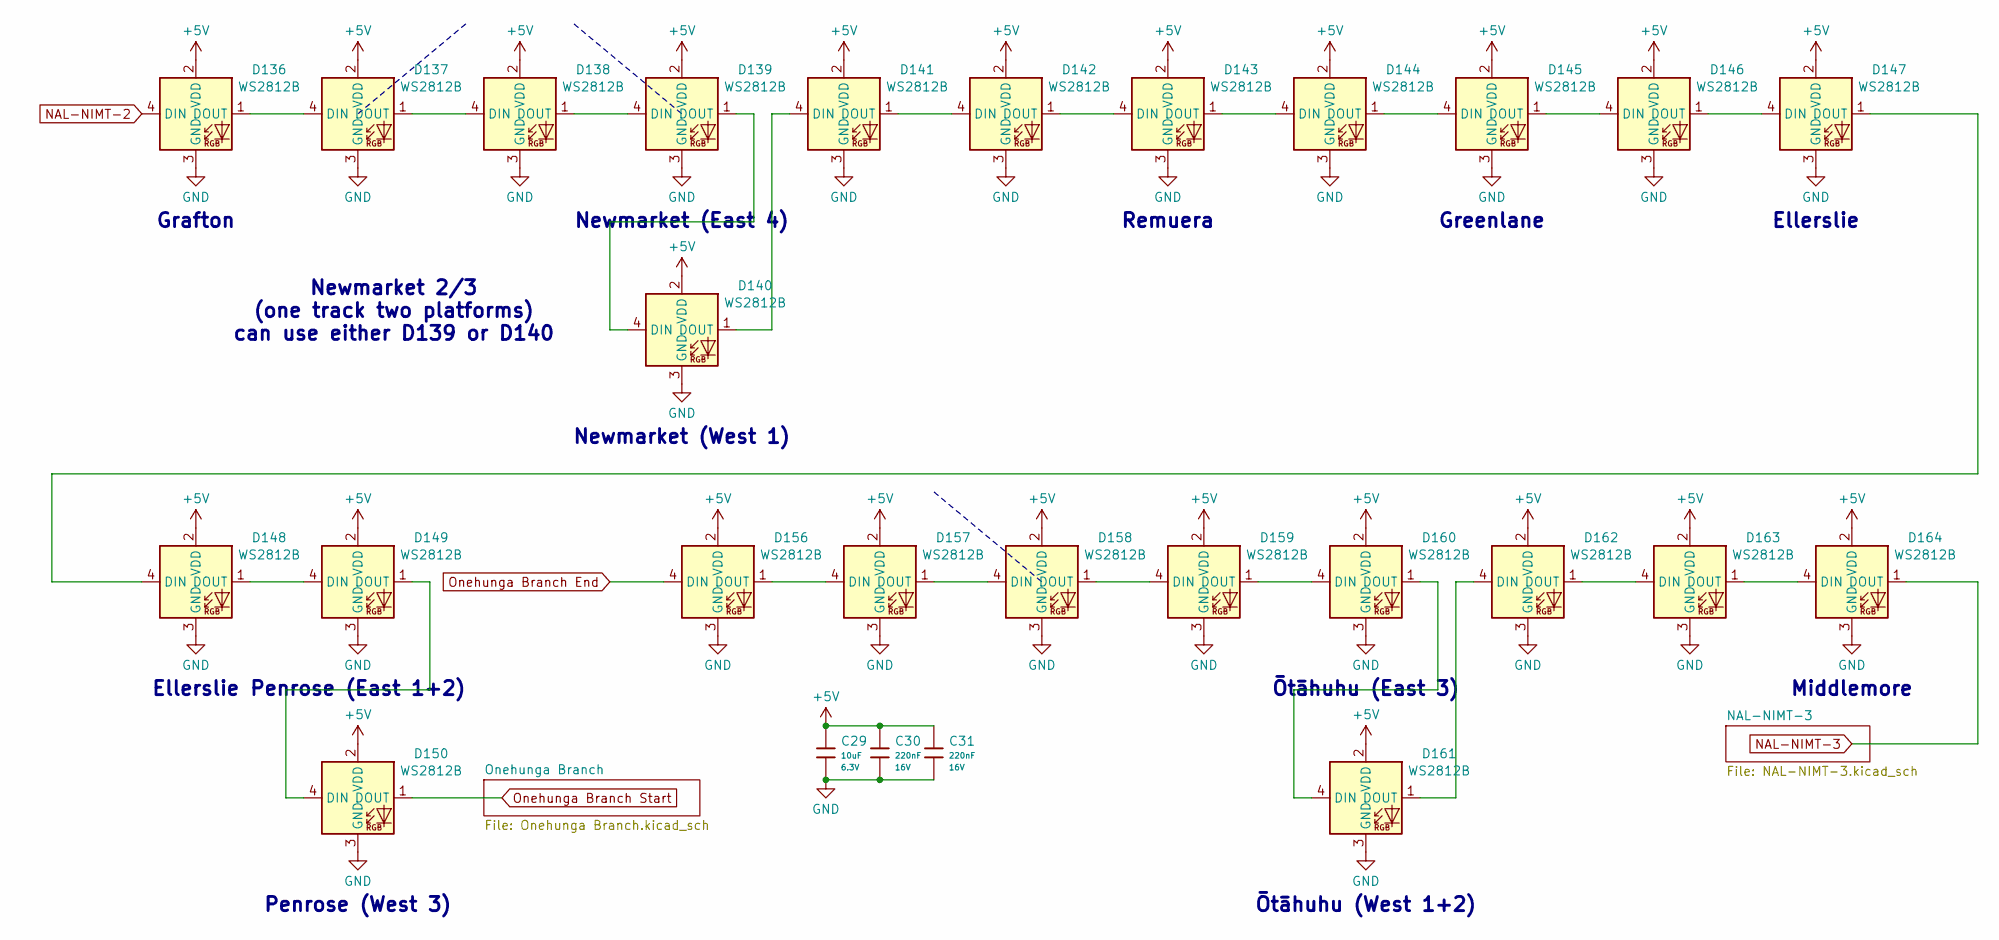
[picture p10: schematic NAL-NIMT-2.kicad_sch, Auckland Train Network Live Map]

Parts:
C29: 10uF; C_0402; Voltage Rated 6.3V; Tolerance ±20%; Part CL05A106MQ5NUNC; LCSC C15525
C30, C31: 220nF; C_0402; Voltage Rated 16V; Tolerance ±10%; Part CL05B224KO5NNNC; LCSC C16772
D136, D137, D138, D139, D140, D141, D142, D143, D144, D145, D146, D147, D148, D149, D150, D156, D157, D158, D159, D160, D161, D162, D163, D164: WS2812B; LED-SMD_4P-L1.6-W1.5_XL-1615RGBC-WS2812B; LCSC C5349954

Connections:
+5V: C29.1, C30.1, C31.1, D136.2 (VDD), D137.2 (VDD), D138.2 (VDD), D139.2 (VDD), D140.2 (VDD), D141.2 (VDD), D142.2 (VDD), D143.2 (VDD), D144.2 (VDD), D145.2 (VDD), D146.2 (VDD), D147.2 (VDD), D148.2 (VDD), D149.2 (VDD), D150.2 (VDD), D156.2 (VDD), D157.2 (VDD), D158.2 (VDD), D159.2 (VDD), D160.2 (VDD), D161.2 (VDD), D162.2 (VDD), D163.2 (VDD), D164.2 (VDD); also elsewhere on the board
GND: C29.2, C30.2, C31.2, D136.3 (GND), D137.3 (GND), D138.3 (GND), D139.3 (GND), D140.3 (GND), D141.3 (GND), D142.3 (GND), D143.3 (GND), D144.3 (GND), D145.3 (GND), D146.3 (GND), D147.3 (GND), D148.3 (GND), D149.3 (GND), D150.3 (GND), D156.3 (GND), D157.3 (GND), D158.3 (GND), D159.3 (GND), D160.3 (GND), D161.3 (GND), D162.3 (GND), D163.3 (GND), D164.3 (GND); also elsewhere on the board
NAL-NIMT-2: D136.4 (DIN); also elsewhere on the board
NAL-NIMT-3: D164.1 (DOUT); also elsewhere on the board
unnamed: D136.1 (DOUT), D137.4 (DIN)
unnamed: D137.1 (DOUT), D138.4 (DIN)
unnamed: D138.1 (DOUT), D139.4 (DIN)
unnamed: D139.1 (DOUT), D140.4 (DIN)
unnamed: D140.1 (DOUT), D141.4 (DIN)
unnamed: D141.1 (DOUT), D142.4 (DIN)
unnamed: D142.1 (DOUT), D143.4 (DIN)
unnamed: D143.1 (DOUT), D144.4 (DIN)
unnamed: D144.1 (DOUT), D145.4 (DIN)
unnamed: D145.1 (DOUT), D146.4 (DIN)
unnamed: D146.1 (DOUT), D147.4 (DIN)
unnamed: D147.1 (DOUT), D148.4 (DIN)
unnamed: D148.1 (DOUT), D149.4 (DIN)
unnamed: D149.1 (DOUT), D150.4 (DIN)
unnamed: D156.1 (DOUT), D157.4 (DIN)
unnamed: D157.1 (DOUT), D158.4 (DIN)
unnamed: D158.1 (DOUT), D159.4 (DIN)
unnamed: D159.1 (DOUT), D160.4 (DIN)
unnamed: D160.1 (DOUT), D161.4 (DIN)
unnamed: D161.1 (DOUT), D162.4 (DIN)
unnamed: D162.1 (DOUT), D163.4 (DIN)
unnamed: D163.1 (DOUT), D164.4 (DIN)
Onehunga Branch End: D156.4 (DIN); also elsewhere on the board
Onehunga Branch Start: D150.1 (DOUT); also elsewhere on the board

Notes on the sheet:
Middlemore
Greenlane
Ōtāhuhu (East 3)
Newmarket 2/3 (one track two platforms) can use either D139 or D140
Ellerslie
Grafton
Newmarket (East 4)
Remuera
Ōtāhuhu (West 1+2)
Newmarket (West 1)
Penrose (West 3)
Penrose (East 1+2)

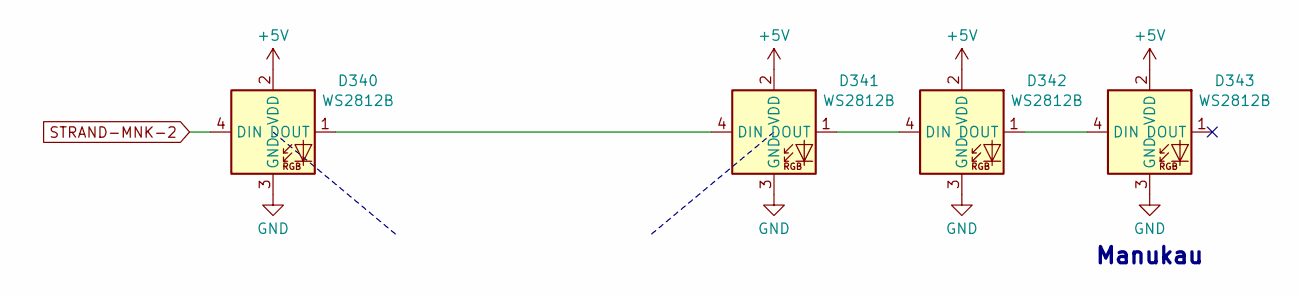
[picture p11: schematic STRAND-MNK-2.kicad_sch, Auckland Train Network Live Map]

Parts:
D340, D341, D342, D343: WS2812B; LED-SMD_4P-L1.6-W1.5_XL-1615RGBC-WS2812B; LCSC C5349954

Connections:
+5V: D340.2 (VDD), D341.2 (VDD), D342.2 (VDD), D343.2 (VDD); also elsewhere on the board
GND: D340.3 (GND), D341.3 (GND), D342.3 (GND), D343.3 (GND); also elsewhere on the board
unnamed: D340.1 (DOUT), D341.4 (DIN)
unnamed: D341.1 (DOUT), D342.4 (DIN)
unnamed: D342.1 (DOUT), D343.4 (DIN)
STRAND-MNK-2: D340.4 (DIN); also elsewhere on the board

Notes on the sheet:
Manukau

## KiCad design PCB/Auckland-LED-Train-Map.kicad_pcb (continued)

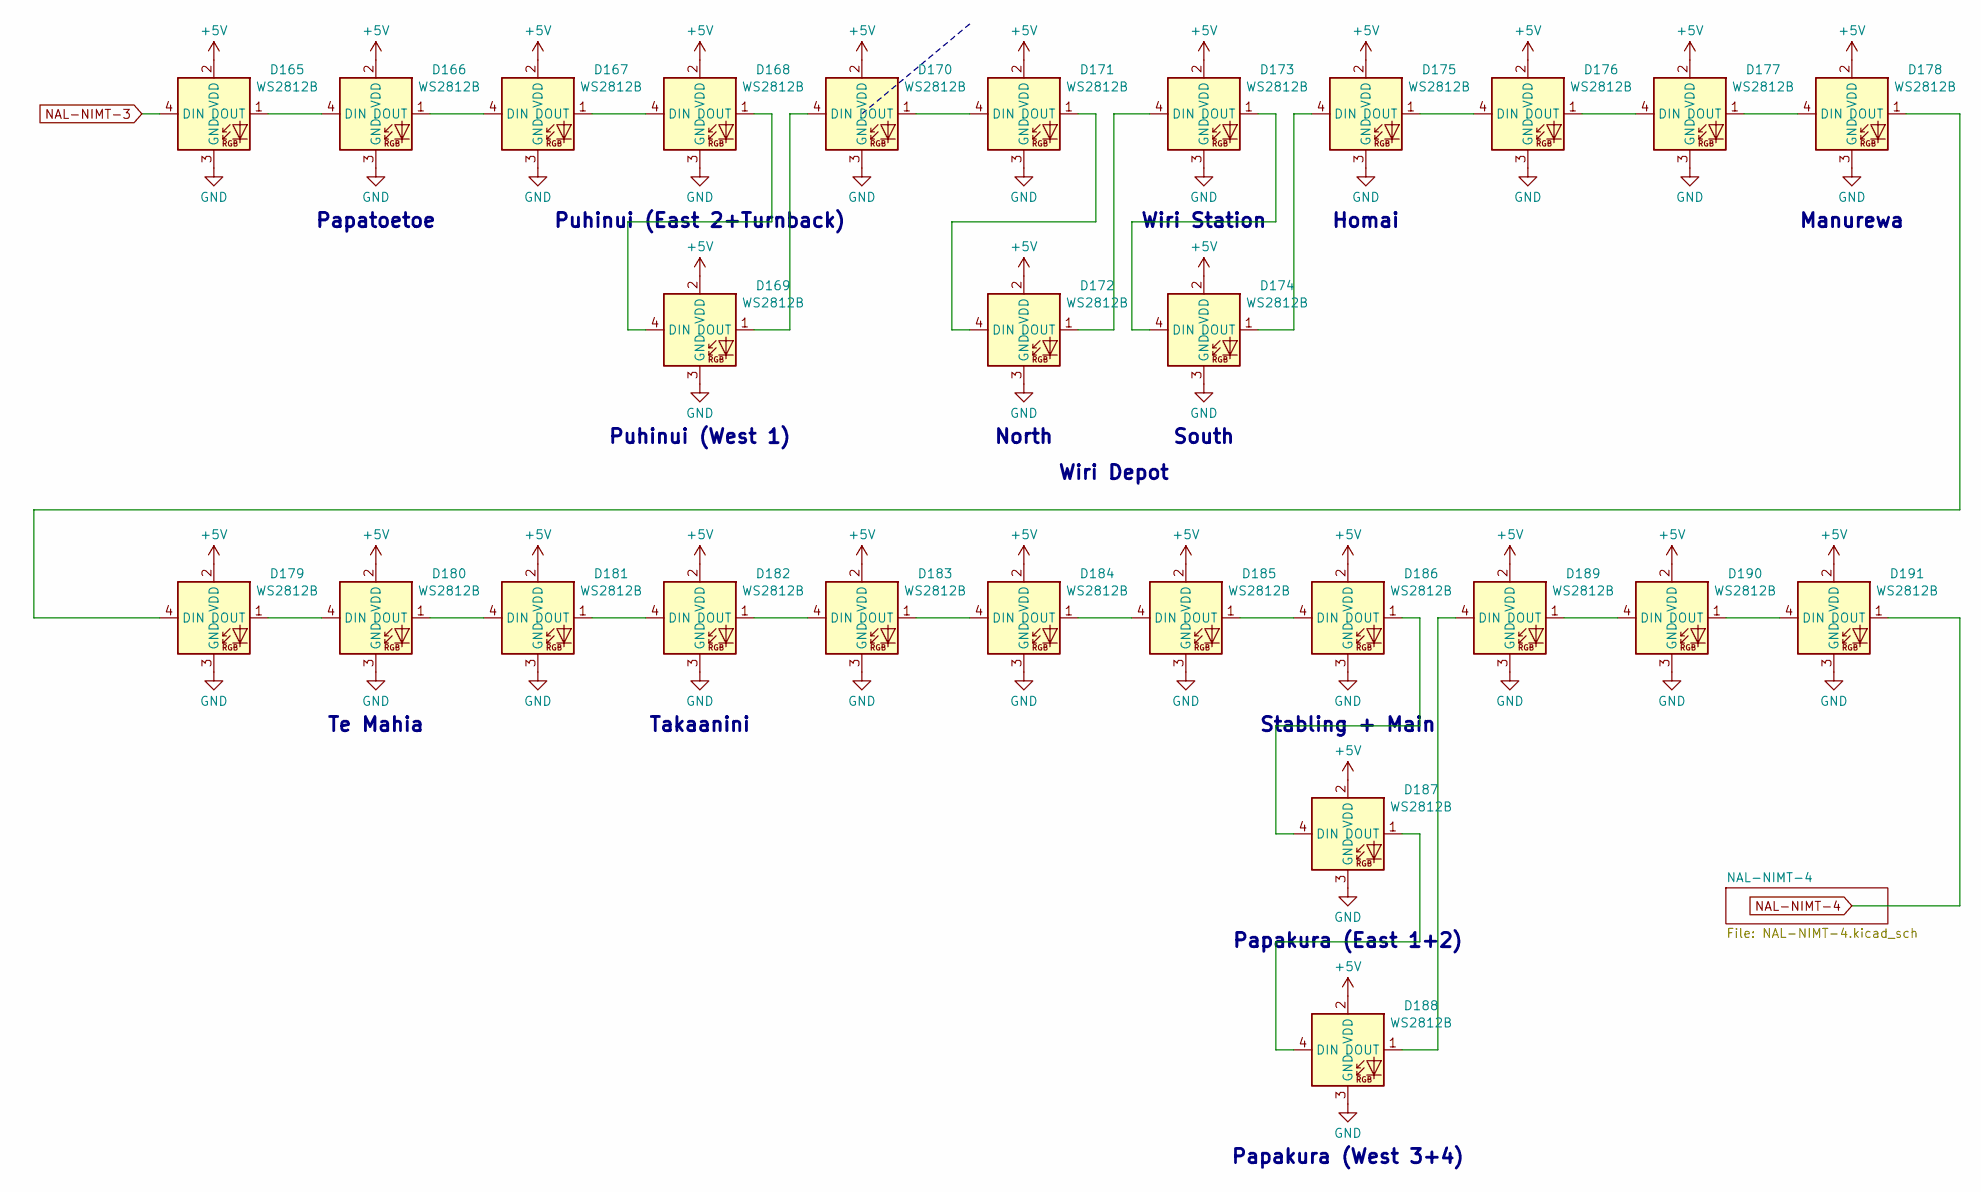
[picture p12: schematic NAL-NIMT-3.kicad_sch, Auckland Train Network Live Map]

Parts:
D165, D166, D167, D168, D169, D170, D171, D172, D173, D174, D175, D176, D177, D178, D179, D180, D181, D182, D183, D184, D185, D186, D187, D188, D189, D190, D191: WS2812B; LED-SMD_4P-L1.6-W1.5_XL-1615RGBC-WS2812B; LCSC C5349954

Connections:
+5V: D165.2 (VDD), D166.2 (VDD), D167.2 (VDD), D168.2 (VDD), D169.2 (VDD), D170.2 (VDD), D171.2 (VDD), D172.2 (VDD), D173.2 (VDD), D174.2 (VDD), D175.2 (VDD), D176.2 (VDD), D177.2 (VDD), D178.2 (VDD), D179.2 (VDD), D180.2 (VDD), D181.2 (VDD), D182.2 (VDD), D183.2 (VDD), D184.2 (VDD), D185.2 (VDD), D186.2 (VDD), D187.2 (VDD), D188.2 (VDD), D189.2 (VDD), D190.2 (VDD), D191.2 (VDD); also elsewhere on the board
GND: D165.3 (GND), D166.3 (GND), D167.3 (GND), D168.3 (GND), D169.3 (GND), D170.3 (GND), D171.3 (GND), D172.3 (GND), D173.3 (GND), D174.3 (GND), D175.3 (GND), D176.3 (GND), D177.3 (GND), D178.3 (GND), D179.3 (GND), D180.3 (GND), D181.3 (GND), D182.3 (GND), D183.3 (GND), D184.3 (GND), D185.3 (GND), D186.3 (GND), D187.3 (GND), D188.3 (GND), D189.3 (GND), D190.3 (GND), D191.3 (GND); also elsewhere on the board
NAL-NIMT-3: D165.4 (DIN); also elsewhere on the board
NAL-NIMT-4: D191.1 (DOUT); also elsewhere on the board
unnamed: D165.1 (DOUT), D166.4 (DIN)
unnamed: D166.1 (DOUT), D167.4 (DIN)
unnamed: D167.1 (DOUT), D168.4 (DIN)
unnamed: D168.1 (DOUT), D169.4 (DIN)
unnamed: D169.1 (DOUT), D170.4 (DIN)
unnamed: D170.1 (DOUT), D171.4 (DIN)
unnamed: D171.1 (DOUT), D172.4 (DIN)
unnamed: D172.1 (DOUT), D173.4 (DIN)
unnamed: D173.1 (DOUT), D174.4 (DIN)
unnamed: D174.1 (DOUT), D175.4 (DIN)
unnamed: D175.1 (DOUT), D176.4 (DIN)
unnamed: D176.1 (DOUT), D177.4 (DIN)
unnamed: D177.1 (DOUT), D178.4 (DIN)
unnamed: D178.1 (DOUT), D179.4 (DIN)
unnamed: D179.1 (DOUT), D180.4 (DIN)
unnamed: D180.1 (DOUT), D181.4 (DIN)
unnamed: D181.1 (DOUT), D182.4 (DIN)
unnamed: D182.1 (DOUT), D183.4 (DIN)
unnamed: D183.1 (DOUT), D184.4 (DIN)
unnamed: D184.1 (DOUT), D185.4 (DIN)
unnamed: D185.1 (DOUT), D186.4 (DIN)
unnamed: D186.1 (DOUT), D187.4 (DIN)
unnamed: D187.1 (DOUT), D188.4 (DIN)
unnamed: D188.1 (DOUT), D189.4 (DIN)
unnamed: D189.1 (DOUT), D190.4 (DIN)
unnamed: D190.1 (DOUT), D191.4 (DIN)

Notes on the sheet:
Homai
Manurewa
Stabling + Main
North
Puhinui (West 1)
Wiri Depot
Te Mahia
Papakura (West 3+4)
South
Takaanini
Puhinui (East 2+Turnback)
Wiri Station
Papatoetoe
Papakura (East 1+2)

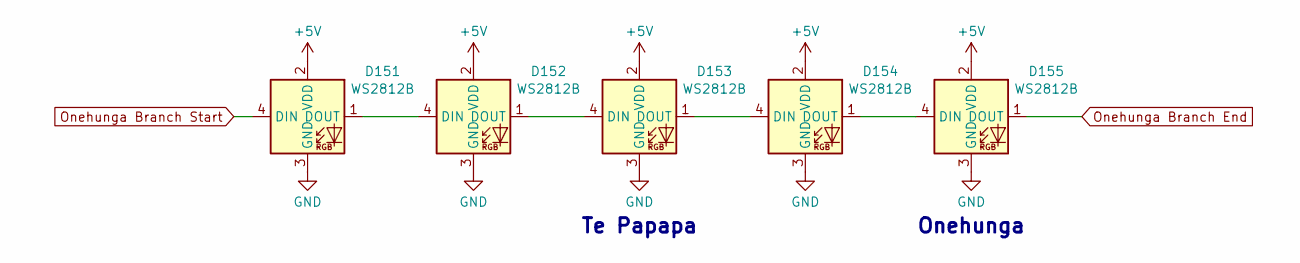
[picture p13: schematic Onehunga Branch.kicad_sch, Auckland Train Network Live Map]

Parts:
D151, D152, D153, D154, D155: WS2812B; LED-SMD_4P-L1.6-W1.5_XL-1615RGBC-WS2812B; LCSC C5349954

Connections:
+5V: D151.2 (VDD), D152.2 (VDD), D153.2 (VDD), D154.2 (VDD), D155.2 (VDD); also elsewhere on the board
GND: D151.3 (GND), D152.3 (GND), D153.3 (GND), D154.3 (GND), D155.3 (GND); also elsewhere on the board
unnamed: D151.1 (DOUT), D152.4 (DIN)
unnamed: D152.1 (DOUT), D153.4 (DIN)
unnamed: D153.1 (DOUT), D154.4 (DIN)
unnamed: D154.1 (DOUT), D155.4 (DIN)
Onehunga Branch End: D155.1 (DOUT); also elsewhere on the board
Onehunga Branch Start: D151.4 (DIN); also elsewhere on the board

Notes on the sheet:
Te Papapa
Onehunga

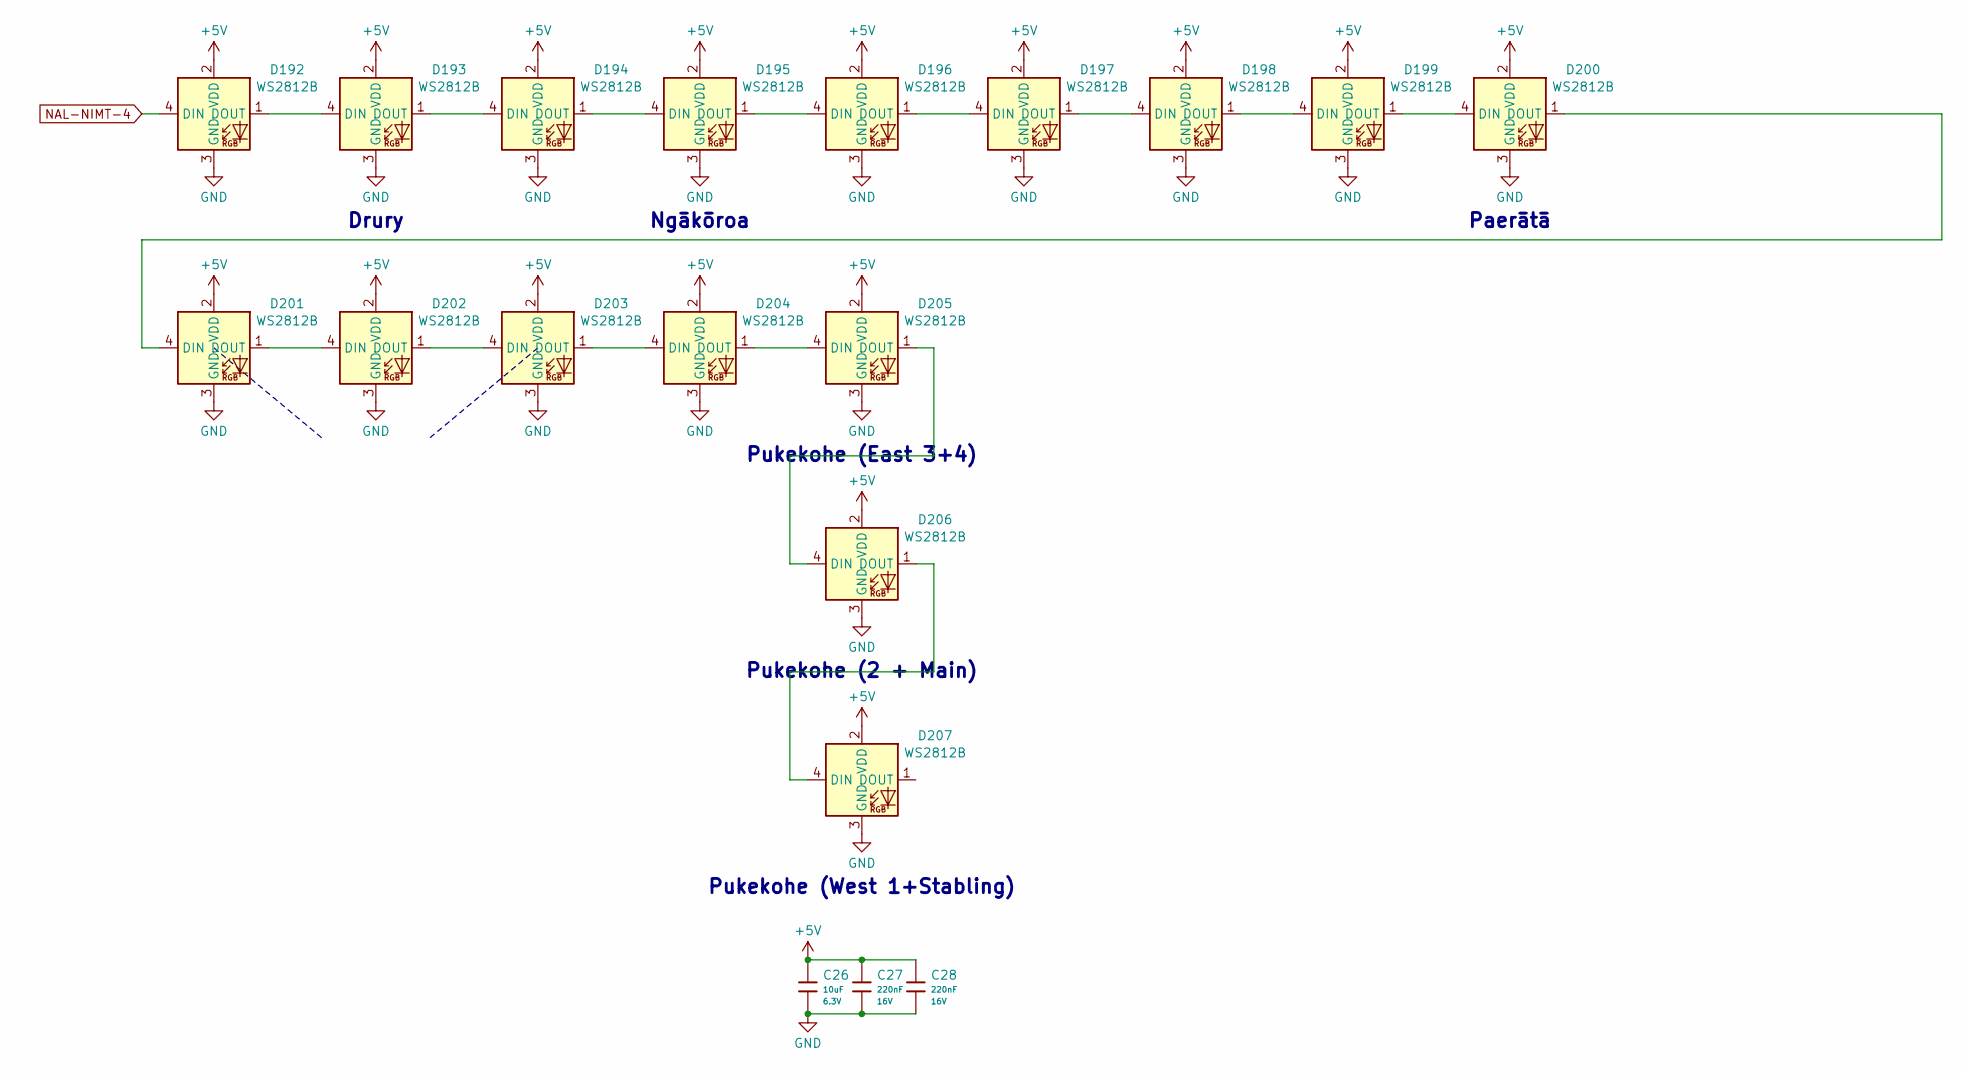
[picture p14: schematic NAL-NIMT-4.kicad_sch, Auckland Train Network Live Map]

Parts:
C26: 10uF; C_0402; Voltage Rated 6.3V; Tolerance ±20%; Part CL05A106MQ5NUNC; LCSC C15525
C27, C28: 220nF; C_0402; Voltage Rated 16V; Tolerance ±10%; Part CL05B224KO5NNNC; LCSC C16772
D192, D193, D194, D195, D196, D197, D198, D199, D200, D201, D202, D203, D204, D205, D206, D207: WS2812B; LED-SMD_4P-L1.6-W1.5_XL-1615RGBC-WS2812B; LCSC C5349954

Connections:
+5V: C26.1, C27.1, C28.1, D192.2 (VDD), D193.2 (VDD), D194.2 (VDD), D195.2 (VDD), D196.2 (VDD), D197.2 (VDD), D198.2 (VDD), D199.2 (VDD), D200.2 (VDD), D201.2 (VDD), D202.2 (VDD), D203.2 (VDD), D204.2 (VDD), D205.2 (VDD), D206.2 (VDD), D207.2 (VDD); also elsewhere on the board
GND: C26.2, C27.2, C28.2, D192.3 (GND), D193.3 (GND), D194.3 (GND), D195.3 (GND), D196.3 (GND), D197.3 (GND), D198.3 (GND), D199.3 (GND), D200.3 (GND), D201.3 (GND), D202.3 (GND), D203.3 (GND), D204.3 (GND), D205.3 (GND), D206.3 (GND), D207.3 (GND); also elsewhere on the board
NAL-NIMT-4: D192.4 (DIN); also elsewhere on the board
unnamed: D192.1 (DOUT), D193.4 (DIN)
unnamed: D193.1 (DOUT), D194.4 (DIN)
unnamed: D194.1 (DOUT), D195.4 (DIN)
unnamed: D195.1 (DOUT), D196.4 (DIN)
unnamed: D196.1 (DOUT), D197.4 (DIN)
unnamed: D197.1 (DOUT), D198.4 (DIN)
unnamed: D198.1 (DOUT), D199.4 (DIN)
unnamed: D199.1 (DOUT), D200.4 (DIN)
unnamed: D200.1 (DOUT), D201.4 (DIN)
unnamed: D201.1 (DOUT), D202.4 (DIN)
unnamed: D202.1 (DOUT), D203.4 (DIN)
unnamed: D203.1 (DOUT), D204.4 (DIN)
unnamed: D204.1 (DOUT), D205.4 (DIN)
unnamed: D205.1 (DOUT), D206.4 (DIN)
unnamed: D206.1 (DOUT), D207.4 (DIN)

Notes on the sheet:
Paerātā
Drury
Pukekohe (2 + Main)
Pukekohe (East 3+4)
Ngākōroa
Pukekohe (West 1+Stabling)

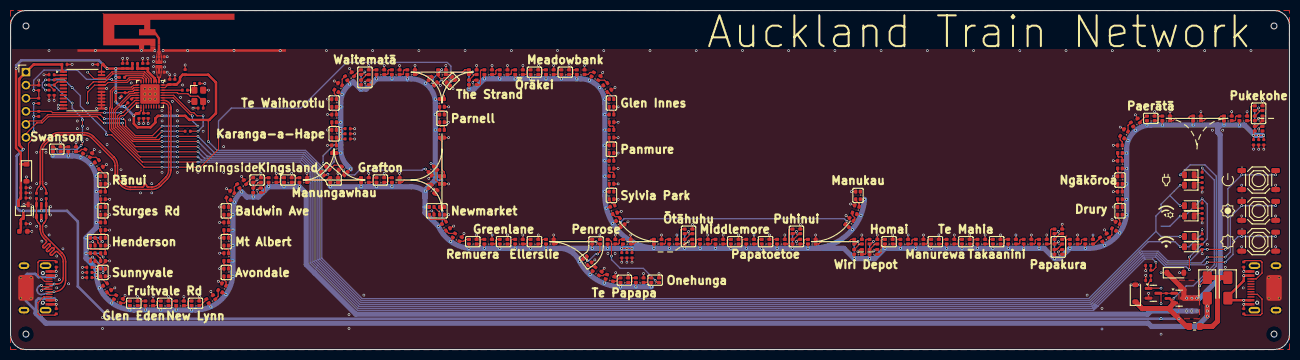
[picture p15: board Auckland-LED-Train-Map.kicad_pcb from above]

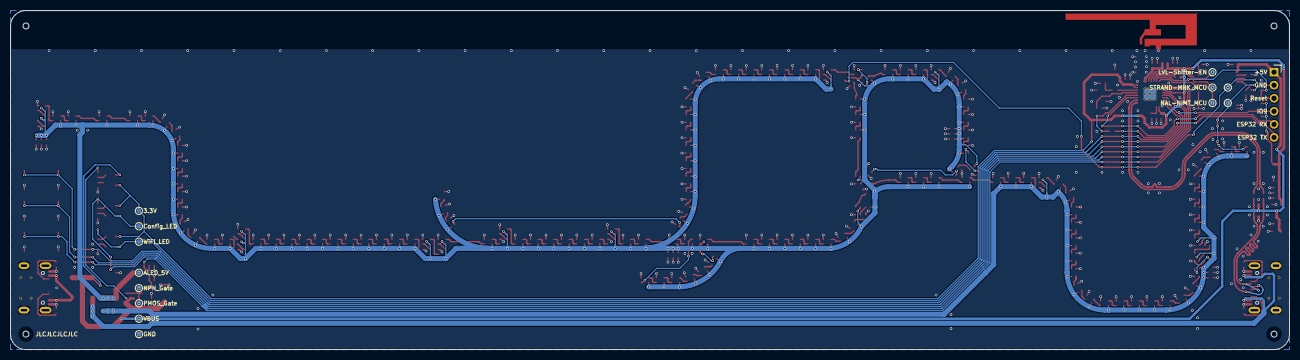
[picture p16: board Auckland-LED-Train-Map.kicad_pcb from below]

Board: 2 copper layers, 249.0 x 66.0 mm, 262 parts (14 on the bottom side), 200 nets.

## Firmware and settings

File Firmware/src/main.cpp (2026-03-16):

#include <Arduino.h>
#include <ArduinoJson.h>
#include <HTTPClient.h>
#include <NeoPixelBus.h>
#include <NeoPixelBusLg.h>
#include <Preferences.h>
#include <WiFi.h>
#include <esp_sntp.h>
#include <time.h>
#include <vector>

#include "WiFiConfig.h"

// Array of server URLs for failover
String serverURLs[] = {
	String("https://led-rails-backend-akldelay.onrender.com/akl-ltm/") + BACKEND_VERSION + ".json", // Render.com server
	String("http://192.168.20.9:3000/akl-ltm/") + BACKEND_VERSION + ".json", // Local server
	String("http://keastudios.co.nz/akl-ltm/") + BACKEND_VERSION + ".json", // OG Server
	String("http://dirksonline.net/akl-ltm/") + BACKEND_VERSION + ".json" // Backup OP Server
};
const int numServers = sizeof(serverURLs) / sizeof(serverURLs[0]);
int currentServerIndex = 0;

const char* ntpServers[] = { "nz.pool.ntp.org", "pool.msltime.measurement.govt.nz", "pool.ntp.org" };

const char* time_zone = "NZST-12NZDT,M9.5.0,M4.1.0/3";

time_t lastMapDrawTime = 0;	 // Tracks the last time the map was drawn
time_t nextFetchTime = 0;	 // Tracks when the next update should occur

// Pins and pixel counts defined in the board file (./boards/)

// I am useing WS2811 timing =>   0:{0.3, 0.95} 1:{0.9, 0.35} Reset:300us
// XL-1615RGBC-WS2812B-S requires 0:{>0.3, >0.9} 1:{>0.9, >0.3} Reset:>200us
NeoPixelBusLg<NeoGrbFeature, NeoEsp32Rmt0Ws2811Method> strandMNK(STRAND_MNK_PIXELS, STRAND_MNK);
NeoPixelBusLg<NeoGrbFeature, NeoEsp32Rmt1Ws2811Method> nalNIMT(NAL_NIMT_PIXELS, NAL_NIMT);

RgbColor black(0, 0, 0);
std::vector<RgbColor> colorTable;
int blockColorIds[512];	 // Array to hold block colors

// --- Data structure for scheduled LED updates ---
struct LedUpdate {
	uint16_t preBlock;
	uint16_t postBlock;
	int colorId;
	time_t timestamp;  // Timestamp for when the update should occur
};

std::vector<LedUpdate> ledUpdateSchedule;

enum statusLedCommand {
	LED_OFF,
	LED_ON_GREEN,
	LED_ON_RED,
	LED_BLINK_GREEN_SLOW,  // 1Hz
	LED_BLINK_GREEN_FAST,  // 5Hz
	LED_BLINK_RED_SLOW,	   // 1Hz
	LED_BLINK_RED_FAST	   // 5Hz
};

enum charlieplexedLedState { GREEN, RED, OFF };

typedef struct {
	uint8_t pin;
	statusLedCommand command;
	bool currentState;
	unsigned long lastToggle;
} statusLed;

TaskHandle_t statusLedTaskHandle;

static unsigned long lastUpdate = 0;
int16_t brightness = 60;
bool ledUpdatePending = false;
bool showNotInServiceTrains = true;

struct Button {
	uint8_t pin;
	volatile unsigned long lastChangeTime;
	volatile bool pendingCheck;
	bool lastState;
};

// Initialize button structures
Button brightnessDownButton = { BRIGHTNESS_DOWN_BUTTON, 0, false, HIGH };
Button brightnessUpButton = { BRIGHTNESS_UP_BUTTON, 0, false, HIGH };
Button powerButton = { POWER_BUTTON, 0, false, HIGH };

// --- (Existing ISR, button check, time, and LED functions) ---
// IRAM_ATTR ensures the ISR is placed in IRAM
void IRAM_ATTR buttonISR(void* arg) {
	Button* button = (Button*)arg;
	button->lastChangeTime = xTaskGetTickCountFromISR() * portTICK_PERIOD_MS;
	button->pendingCheck = true;
}

void checkButton(Button* button) {
    if (button->pendingCheck && (millis() - button->lastChangeTime) >= DEBOUNCE_DELAY) {
        bool currentState = digitalRead(button->pin);
        if (currentState != button->lastState) {
            button->lastState = currentState;
            if (currentState == LOW) {	// Assuming active-low configuration
                // Handle button press
                if (button->pin == BRIGHTNESS_DOWN_BUTTON && digitalRead(BRIGHTNESS_UP_BUTTON) == LOW) {
                    // Handle both brightness buttons being held down
                    showNotInServiceTrains = !showNotInServiceTrains;
                    Serial.printf("Not-in-service train visibility toggled: %s\n", showNotInServiceTrains ? "ON" : "OFF");
                    ledUpdatePending = true;
                    // Consume the check for the other button to prevent double execution
                    brightnessUpButton.pendingCheck = false;
                    return;
                } else if (button->pin == BRIGHTNESS_UP_BUTTON && digitalRead(BRIGHTNESS_DOWN_BUTTON) == LOW) {
                    // This case is handled by the one above to avoid running twice.
                    // We just need to consume the check.
                    brightnessDownButton.pendingCheck = false;
                    return;
                }
                switch (button->pin) {
                    case BRIGHTNESS_DOWN_BUTTON:
                        Serial.print("Brightness Down pressed ");
                        brightness -= 20;
                        break;
                    case BRIGHTNESS_UP_BUTTON:
                        Serial.print("Brightness Up pressed ");
                        brightness += 20;
                        break;
                    case POWER_BUTTON:
                        Serial.print("Power button pressed ");
                        brightness = (brightness == 0) ? 250 : 0;  // Toggle brightness
                        break;
                    default:
                        Serial.printf("Unknown button pressed on pin %d\n", button->pin);
                        return;	 // Exit if an unknown button is pressed
                }

				// Ensure brightness stays within bounds
				brightness = (brightness > 0) ? constrain(brightness, 20, 250) : 0;

				// Save brightness to preferences
				preferences.begin("brightness");
				if (preferences.getInt("brightness") != brightness) {
					preferences.putInt("brightness", brightness);
				}
				preferences.end();

				// Update the LEDs
				strandMNK.SetLuminance(brightness);
				nalNIMT.SetLuminance(brightness);

				Serial.printf("brightness now at: %i/255\n", brightness);
				ledUpdatePending = true;
			}
		}
		button->pendingCheck = false;
	}
}

const char* getLocalTime(time_t epoch) {
	struct tm timeinfo;
	static char buffer[64];
	struct timeval tv;

	// Convert epoch to local time
	if (!localtime_r(&epoch, &timeinfo)) {
		return "No time available";
	}
	gettimeofday(&tv, nullptr);
	int ms = tv.tv_usec / 1000;
	if (strftime(buffer, sizeof(buffer), "%H:%M:%S", &timeinfo)) {
		snprintf(buffer + strlen(buffer), sizeof(buffer) - strlen(buffer), ".%03d", ms);
		return buffer;
	}
	return "Format error";
}

void timeavailable(struct timeval* t) {
	Serial.println("NTP Synced");
}

void setCharlieplexedLED(uint8_t pin, charlieplexedLedState state) {
	switch (state) {
		case GREEN:
			pinMode(pin, OUTPUT);
			digitalWrite(pin, HIGH);
			break;

		case RED:
			pinMode(pin, OUTPUT);
			digitalWrite(pin, LOW);
			break;

		case OFF:
			// Set as input (High Resistance) to disable output driver
			pinMode(pin, INPUT);
			break;
	}
}

void statusLedManagerTask(void* pvParameters) {
	statusLed leds[] = { { WIFI_LED_PIN, LED_OFF, false, 0 }, { CONFIG_LED_PIN, LED_OFF, false, 0 } };
	const int numLeds = sizeof(leds) / sizeof(leds[0]);

	while (1) {
		// Check for notifications
		uint32_t notification;
		if (xTaskNotifyWait(0, ULONG_MAX, &notification, 0) == pdTRUE) {
			uint8_t pin = notification >> 24;
			statusLedCommand cmd = statusLedCommand((notification >> 16) & 0xFF);

			for (int i = 0; i < numLeds; i++) {
				if (leds[i].pin == pin) {
					leds[i].command = cmd;
					// Immediate response for non-blinking states
					if (cmd == LED_ON_GREEN || cmd == LED_ON_RED || cmd == LED_OFF) {
						setCharlieplexedLED(pin, (cmd == LED_ON_GREEN) ? GREEN : (cmd == LED_ON_RED) ? RED : OFF);
					}
					break;
				}
			}
		}

		// Handle blinking
		unsigned long now = millis();
		for (int i = 0; i < numLeds; i++) {
			if (leds[i].command >= LED_BLINK_GREEN_SLOW) {	// All blink commands
				// Extract blink parameters from command
				const bool isGreen = (leds[i].command == LED_BLINK_GREEN_SLOW || leds[i].command == LED_BLINK_GREEN_FAST);
				const bool isRed = (leds[i].command == LED_BLINK_RED_SLOW || leds[i].command == LED_BLINK_RED_FAST);
				const bool isSlow = (leds[i].command == LED_BLINK_GREEN_SLOW || leds[i].command == LED_BLINK_RED_SLOW);

				if (isGreen || isRed) {
					const int interval = isSlow ? 500 : 100;  // 1Hz or 5Hz
					const charlieplexedLedState color = isGreen ? GREEN : RED;

					if (now - leds[i].lastToggle >= interval) {
						leds[i].currentState = !leds[i].currentState;
						setCharlieplexedLED(leds[i].pin, leds[i].currentState ? color : OFF);
						leds[i].lastToggle = now;
					}
				}
			}
		}

		vTaskDelay(pdMS_TO_TICKS(25));
	}
}

void setStatusLedState(uint8_t pin, statusLedCommand command) {
	uint32_t notification = (pin << 24) | (command << 16);
	xTaskNotify(statusLedTaskHandle, notification, eSetValueWithOverwrite);
}

const char* getSystemInfo() {
	static char buffer[255];
	FlashMode_t mode = (FlashMode_t)ESP.getFlashChipMode();
	const char* flash_mode_str;

	// Convert flash mode to human-readable string
	switch (mode) {
		case FM_QIO: flash_mode_str = "Quad I/O (QIO)"; break;
		case FM_QOUT: flash_mode_str = "Quad Output (QOUT)"; break;
		case FM_DIO: flash_mode_str = "Dual I/O (DIO)"; break;
		case FM_DOUT: flash_mode_str = "Dual Output (DOUT)"; break;
		case FM_FAST_READ: flash_mode_str = "Fast Read"; break;
		case FM_SLOW_READ: flash_mode_str = "Slow Read"; break;
		case FM_UNKNOWN:
		default: flash_mode_str = "Unknown"; break;
	}

	snprintf(
		buffer,
		sizeof(buffer),
		"\n%s\n"
		"%s-Rev%d\n"
		"%d Core @ %dMHz\n"
		"%dMiB Flash @ %dMHz in %s Mode\n"
		"RAM Heap: %dkiB\n"
		"IDF SDK: %s\n",
		ARDUINO_BOARD,
		ESP.getChipModel(),
		ESP.getChipRevision(),
		ESP.getChipCores(),
		ESP.getCpuFreqMHz(),
		ESP.getFlashChipSize() / (1024 * 1024),
		ESP.getFlashChipSpeed() / (1000 * 1000),
		flash_mode_str,
		ESP.getHeapSize() / 1024,
		ESP.getSdkVersion());

	return buffer;
}

String downloadJSON() {
	HTTPClient http;
	String payload;

	for (int i = 0; i < numServers; i++) {
		int serverIndex = (currentServerIndex + i) % numServers;
		String url = serverURLs[serverIndex];
		Serial.printf("Fetching from %s\n", url.c_str());
		http.setTimeout(10000);	 // Set timeout to 10 seconds per server
		http.setFollowRedirects(HTTPC_FORCE_FOLLOW_REDIRECTS);
		http.begin(url);

		int httpCode = http.GET();
		if (httpCode == HTTP_CODE_OK) {
			payload = http.getString();
			http.end();
			//currentServerIndex = serverIndex;  // Update to the successful server
			currentServerIndex = 0;  // Always try from the first server (development mode - useful for local server testing)
			return payload;
		} else {
			Serial.printf("Fetch from %s returned: %i (%s)\n", url.c_str(), httpCode, http.errorToString(httpCode).c_str());
			http.end();
		}
	}
	return String();
}

void setBlockColor(uint16_t block, int colorId) {
	if (colorId < blockColorIds[block]) {
		return;	 // Do not update if the block if it is low priority
	}

	blockColorIds[block] = colorId;	 // Update the color ID for the block if it's higher

	// Set the color on the appropriate strand based on the block number
	if (block >= 100 && block < 100 + NAL_NIMT_PIXELS) {
		nalNIMT.SetPixelColor(block - 100, colorTable[blockColorIds[block]]);
	} else if (block >= 300 && block < 300 + STRAND_MNK_PIXELS) {
		strandMNK.SetPixelColor(block - 300, colorTable[blockColorIds[block]]);
	} else {
		Serial.printf("Block %d is out of range for both strands.\n", block);
	}
}

void drawMap(time_t epoch) {
	// Clear both strands
	nalNIMT.ClearTo(black);
	strandMNK.ClearTo(black);
	// Reset the blocks array
	for (int i = 0; i < 512; i++) {
		blockColorIds[i] = 0;  // Reset all blocks to black
	}

    // Draw the map based on the current LED update schedule
    for (const auto& update : ledUpdateSchedule) {
        // Skip "not in service" trains (colorId is 0) if they are toggled off
        if (!showNotInServiceTrains && update.colorId == 0) {
            continue;
        }
        if (epoch >= update.timestamp) {
            setBlockColor(update.postBlock, update.colorId);
        } else {
            setBlockColor(update.preBlock, update.colorId);
        }
    }

	// Show the updates on both strands
	strandMNK.Show();

	// Allow time for the strand to be sent out (Not needed but might reduce interference)
	vTaskDelay(pdMS_TO_TICKS(int(0.03 * STRAND_MNK_PIXELS) + 1));

	nalNIMT.Show();

	lastMapDrawTime = epoch;  // Update the last draw time
}

void parseLEDMap(const String& downloadedJson) {
	JsonDocument doc;
	DeserializationError error = deserializeJson(doc, downloadedJson);

	if (error) {
		Serial.printf("JSON parse error: %s\n", error.c_str());
		return;
	}

	String version = doc["version"] | "";
	time_t baseTimestamp = doc["timestamp"] | 0;
	int updateOffset = doc["update"] | 0;
	JsonObject colors = doc["colors"];
	JsonArray updates = doc["updates"];

	if (baseTimestamp + updateOffset > nextFetchTime) {
		nextFetchTime = baseTimestamp + updateOffset;
	} else {
		Serial.println("Fetched the same data twice");
		return;	 // No need to update if the data is the same
	}

	if (String(BACKEND_VERSION) != version) {
		Serial.printf("Backend version mismatch: expected %s, got %s\n", BACKEND_VERSION, version.c_str());
	}

	// Serial.printf("%ld Base timestamp: %ld, Update offset: %d, Next fetch time: %ld\n",
	// 			  time(nullptr),
	// 			  baseTimestamp,
	// 			  updateOffset,
	// 			  nextFetchTime);

	// Populate colorTable from the JSON colors object
	colorTable.clear();
	for (JsonPair kv : colors) {
		JsonArray rgb = kv.value().as<JsonArray>();
		colorTable.push_back(RgbColor(rgb[0] | 0, rgb[1] | 0, rgb[2] | 0));
	}

	ledUpdateSchedule.clear();
	for (JsonObject update : updates) {
		JsonArray blocks = update["b"];
		int colorId = update["c"];
		int offset = update["t"];

		// Schedule color update
		LedUpdate ledUpdate;
		ledUpdate.preBlock = blocks[0];
		ledUpdate.postBlock = blocks[1];
		if (offset > 0) {
			ledUpdate.timestamp = baseTimestamp + offset;
		} else {
			ledUpdate.timestamp = 0;
		}
		ledUpdate.colorId = colorId;
		ledUpdateSchedule.push_back(ledUpdate);
	}

	ledUpdatePending = true;  // Mark that an update is pending
}

void onCdcRxEvent(void* arg, esp_event_base_t event_base, int32_t event_id, void* event_data) {
	improvSerial.handleSerial();
}

void setup() {
	xTaskCreate(statusLedManagerTask, "Status LED Manager", 1024, NULL, 1, &statusLedTaskHandle);

	// Hardware Serial
	Serial0.begin(115200);

	// USB Serial
	Serial.begin();
	Serial.setDebugOutput(true);
	Serial.onEvent(ARDUINO_HW_CDC_RX_EVENT, onCdcRxEvent);

	pinMode(LVL_Shifter_EN, OUTPUT);
	digitalWrite(LVL_Shifter_EN, HIGH);	 //Disable LVL Shifter
	pinMode(LED_5V_EN, OUTPUT);
	digitalWrite(LED_5V_EN, LOW);  //Disable 5V Power

	strandMNK.Begin();
	strandMNK.ClearTo(black);
	nalNIMT.Begin();
	nalNIMT.ClearTo(black);

	digitalWrite(LVL_Shifter_EN, LOW);	//Enable LVL Shifter
	digitalWrite(LED_5V_EN, HIGH);		//Enable 5V Power

	nalNIMT.Show();
	strandMNK.Show();

	// Set initial brightness
	preferences.begin("brightness");
	brightness = preferences.getInt("brightness", brightness);
	preferences.end();
	strandMNK.SetLuminance(brightness);
	nalNIMT.SetLuminance(brightness);

// Factory test mode
#if defined(FACTORY_TEST)
	preferences.begin("factory_test");
	if (preferences.getBool("passed", false) == false) {  // Check if factory test mode has been passed
		preferences.putBool("passed", true);			  // Set factory test mode as passed
		preferences.end();

		while (true) {
			Serial.println("Factory test mode enabled");

			strandMNK.ClearTo(RgbColor(255, 0, 0));
			nalNIMT.ClearTo(RgbColor(255, 0, 0));
			strandMNK.Show();
			nalNIMT.Show();
			vTaskDelay(pdMS_TO_TICKS(1000));

			strandMNK.ClearTo(RgbColor(0, 255, 0));
			nalNIMT.ClearTo(RgbColor(0, 255, 0));
			strandMNK.Show();
			nalNIMT.Show();
			vTaskDelay(pdMS_TO_TICKS(1000));

			strandMNK.ClearTo(RgbColor(0, 0, 255));
			nalNIMT.ClearTo(RgbColor(0, 0, 255));
			strandMNK.Show();
			nalNIMT.Show();
			vTaskDelay(pdMS_TO_TICKS(1000));
		}
	}
	preferences.end();
#endif

	// Button initialization
	pinMode(brightnessDownButton.pin, INPUT_PULLUP);
	pinMode(brightnessUpButton.pin, INPUT_PULLUP);
	pinMode(powerButton.pin, INPUT_PULLUP);

	// Attach interrupts with debouncing
	attachInterruptArg(digitalPinToInterrupt(BRIGHTNESS_DOWN_BUTTON), buttonISR, &brightnessDownButton, CHANGE);
	attachInterruptArg(digitalPinToInterrupt(BRIGHTNESS_UP_BUTTON), buttonISR, &brightnessUpButton, CHANGE);
	attachInterruptArg(digitalPinToInterrupt(POWER_BUTTON), buttonISR, &powerButton, CHANGE);

	Serial.println(getSystemInfo());

	// --- Time Setup ---
	sntp_set_time_sync_notification_cb(timeavailable);
	sntp_set_sync_interval(1000 * 60 * 15);	 // Set sync interval to 15 minutes
	sntp_set_sync_mode(SNTP_SYNC_MODE_IMMED);
	configTzTime(time_zone, ntpServers[0], ntpServers[1], ntpServers[2]);

	// --- WiFi Setup ---
	setStatusLedState(WIFI_LED_PIN, LED_BLINK_GREEN_FAST);
	WiFi.mode(WIFI_STA);
	WiFi.setTxPower(WIFI_POWER_15dBm);	// Set WiFi power to avoid brownouts
	WiFi.disconnect();

	WiFiImprovSetup();

	Serial.println(getSystemInfo());
}

void loop() {
	handleWiFiImprov();			   // Handle WiFi credentials setup via WebSerial
	time_t epoch = time(nullptr);  // Get current time

	if (WiFi.status() == WL_CONNECTED) {
		setStatusLedState(WIFI_LED_PIN, LED_ON_GREEN);

		// --- Fetch new data periodically ---
		if (epoch > nextFetchTime) {

			String downloadedJson = downloadJSON();
			if (downloadedJson.length() > 0) {
				setStatusLedState(CONFIG_LED_PIN, LED_ON_GREEN);
				parseLEDMap(downloadedJson);  // This populates/updates the schedule
			} else {
				Serial.println("All servers failed to provide data.");
				setStatusLedState(CONFIG_LED_PIN, LED_ON_RED);
			}

			nextFetchTime = max(nextFetchTime, epoch + 6);	// Ensure we don't fetch too frequently

			Serial.printf("%s MCU:%2.0f°C  WiFi:%idBm\n", getLocalTime(epoch), temperatureRead(), WiFi.RSSI());
			Serial.flush();
		}

		// --- Handle button presses ---
		checkButton(&brightnessDownButton);
		checkButton(&brightnessUpButton);
		checkButton(&powerButton);

		// --- Push updates to the LED strips only if changes were made ---
		if (ledUpdatePending || lastMapDrawTime < epoch) {
			drawMap(epoch);	 // Draw the map with the current updates
			ledUpdatePending = false;
		}

	} else {
		setStatusLedState(WIFI_LED_PIN, LED_ON_RED);
	}
	vTaskDelay(pdMS_TO_TICKS(10));	// Delay to yield to other tasks
}

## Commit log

2025-04-13 Long Version Checkpoint
    [Auckland-LED-Train-Map.kicad_pcb, Auckland-LED-Train-Map.kicad_sch, MNK-CRL-1.kicad_sch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]
2025-04-14 PCB Checkpoint
    [Auckland-LED-Train-Map.kicad_pcb, Auckland-LED-Train-Map.kicad_sch, NAL-NIMT-1.kicad_sch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]
2025-04-15 - Remove JLCPCB Outputs - V1 RC1
    [Auckland-LED-Train-Map-CuBottom.gbr, Auckland-LED-Train-Map-CuTop.gbr, Auckland-LED-Train-Map-EdgeCuts.gbr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]
2025-04-16 - V1 RC2 - Add icons
    [Auckland-LED-Train-Map.kicad_pcb, Auckland-LED-Train-Map.kicad_sch, NAL-NIMT-1.kicad_sch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]
2025-04-16 Remove Empty Schematic
    [MNK-CRL-1.kicad_sch]
2025-04-27 - Add Readme - V1 RC3 PCB - Tidy up Schematic - Add Datasheets
    [Auckland-LED-Train-Map.kicad_pcb, Auckland-LED-Train-Map.kicad_sch, NAL-NIMT-1.kicad_sch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]
2025-04-27 Add Schematic to README
2025-04-28 Fix charlieplexed LEDs D10 and D11
    [Auckland-LED-Train-Map.kicad_pcb, Auckland-LED-Train-Map.kicad_sch]
2025-04-28 Add changes suggested from reddit
    [Auckland-LED-Train-Map.kicad_pcb, Auckland-LED-Train-Map.kicad_sch, JLCPCB_Rotations.csv]
2025-05-15 Final tweaks for V1.0.0
    [Auckland-LED-Train-Map.kicad_sch, NAL-NIMT-1.kicad_sch, NAL-NIMT-2.kicad_sch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]
2025-05-15 Fix U3 Footprint
    [Auckland-LED-Train-Map.kicad_sch]
2025-05-22 - Alpha V1.0.0 Firmware - Fix V1.0.0 spelling mistakes
    [JLCPCB_Rotations.csv]
2025-05-25 Refactor WiFi network handling and add button debouncing functionality
2025-05-26 Implement status LED task, add gamma correction, update clang-format settings
    [main.cpp]
2025-05-29 Enhance LED control and time synchronization features; update JSON parsing and server handling
2025-05-31 Refactor status LED management and enhance WiFi connection reliability; increase timeout and set transmission power
2025-06-06 Add initial web installer for Auckland LED Rail Map
    - Created HTML interface for flashing and configuring the device.
    - Added manifest file for firmware installation.
    - Included binary firmware file for the device.
    - Added support for wifi-improv to the firmware
    [default_4MB.csv]
2025-06-06 Fix deployment script to create specific directory for Auckland LED Rail Map and update firmware handling
2025-06-16 Auckland-V1.1-PCB (#2)
    [Auckland-LED-Train-Map.kicad_sch, NAL-NIMT-2.kicad_sch, NAL-NIMT-3.kicad_sch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]
2025-06-16 Add 3d printed stand and instructions
    [akl-ltm-stand.step]
2025-06-23 V1.1.0 PCB
    [Auckland-LED-Train-Map.kicad_sch, NAL-NIMT-1.kicad_sch, NAL-NIMT-2.kicad_sch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]
2025-06-29 Update to meet OSHWA Certification
    [Auckland-LED-Train-Map.kicad_sch, BOM.csv, NAL-NIMT-1.kicad_sch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]
2025-06-30 Add factory test mode and improve brightness handling
    - Introduced factory test mode with LED color cycling for diagnostics.
    - Enhanced brightness management by saving and retrieving brightness settings using preferences.
    - Updated platformio.ini to include factory test environment.
2025-10-16 Add toggle for NIS train visibility when press both brightness buttons.

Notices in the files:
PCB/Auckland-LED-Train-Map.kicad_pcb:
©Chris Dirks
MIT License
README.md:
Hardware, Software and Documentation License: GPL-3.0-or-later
